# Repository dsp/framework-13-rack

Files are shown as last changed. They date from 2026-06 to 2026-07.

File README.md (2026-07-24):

# Framework 13 Mainboard — 3-Bay 1U Rack

A 19" EIA-310 1U rack that holds three Framework Laptop 13 mainboards. All parts print
without supports on a Bambu Lab H2D (325 × 320 × 325 mm). Dimensions come from
Framework's published CAD and from measurements of a physical board.

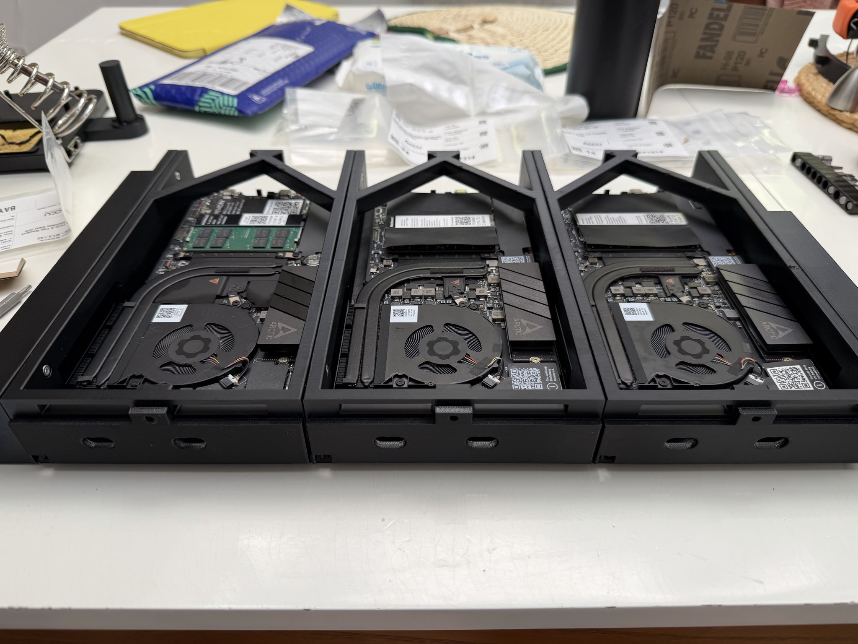
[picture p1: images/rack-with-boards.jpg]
Three Framework 13 mainboards installed in the rack


## Contents

- `stl/` — print-ready STLs, exported 2026-07-06
- `scripts/rebuild_all.py` — parametric source for all parts. It rebuilds the model in a
  fresh Fusion 360 document; set `EXPORT_STL = True` to export. Where the spec and the
  script disagree, the script is authoritative.
- `design-docs/SPEC-RevB.md` — design spec with all dimensions, stack-ups, and rationale.
  The errata blocks at the top supersede the body and record the design's revision history.
- `design-docs/framework-cad/` — Framework's reference CAD (tray STL, board drawing
  PDF/DXF, case STEP) and the scripts used to measure it
- `SCREWS.txt` — hardware list and fastener notes
- `images/` — photos of the assembled rack
- `framework.jpg` — top-view photo of the mainboard, used to locate the cooler fin stack

## Parts

| Part | Qty | Print orientation | Supports |
|---|---|---|---|
| BayModule — rack tray | 3 | standing on front face (Z = 248) | none; 8–10 mm brim |
| CarrierTray — board sled | 3 | flat, plate on bed (Z = 34.5) | none |
| SideHolderLeft — exhaust duct + rack ear | 1 | standing on front face | none |
| SideHolderRight — intake plenum + rack ear | 1 | standing on front face | none |
| RetainerPeg — board hold-down | 9 + spares | head down on bed | none |

Print in PETG or PETG-CF with 4 walls and 30–40% infill. A standard PETG profile at
0.4 mm layers works; the spec assumed 0.2 mm but the parts don't need it.

Bays printed from STLs older than 2026-07-06 have their wall vents behind the cooler
instead of over it; reprint them before running boards under load.

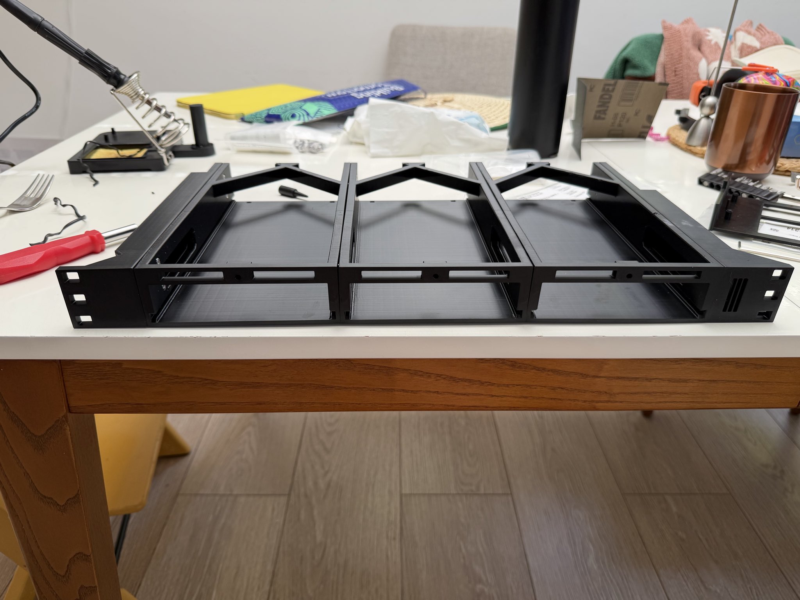
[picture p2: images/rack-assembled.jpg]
The assembled three-bay rack, front view


## Assembly

The full sequence is in SPEC-RevB.md §7; hardware is listed in SCREWS.txt.

1. Set "Power on AC attach" in each board's BIOS before racking. The power switch is
   unreachable once the board is in the rack.
2. Press the heat-set inserts: five M3 per bay (four seam, one header), four M3 in the
   left holder.
3. Bolt the bays together left to right with M3×8 screws and Ø3×8 dowel pins. Drive seam
   screws from inside the right-hand module of each pair. The left holder attaches from
   inside bay 1, the right holder from outside through its counterbores.
4. Mount each board RAM/cooler-side up on its carrier: drop it into the cage onto the
   five standoffs, then press RetainerPegs through two or three mounting holes. Two
   expansion cards face front, two face rear; USB-C power enters at the rear.
5. Slide each carrier in until the left-edge latch clicks, then lock it with its M3×8
   thumbscrew.
6. Rack with six M6 screws and cage nuts. Back the printed ears with 1.5 mm metal plates;
   tighten only until snug. Support the rear of any rack that travels.

## Board mounting

The carrier locates the board with two side nubs on the card-free long edges (0.2 mm
clearance per side) and front/rear stops between the card bays (0.5 mm). RetainerPegs
hold it down: a Ø4.2 head over the screw keep-out and a tapered Ø1.85→1.55 shaft that
press-fits into the Ø1.7 standoff pilot. The nubs and stops bear only on the board's
edges, and peg heads land where Framework's own screw heads sit. Print spare pegs; pry
under the head to remove one. The same pilots accept M2×6 self-tapping screws
(see SCREWS.txt).

The board sits component-side up at h16.5, its laptop orientation, with expansion cards
hanging below. Standard cards (5.4 mm below the PCB) clear the carrier floor by 3.1 mm;
Framework's Ethernet card (~7.4 mm) clears by about 1.1 mm. Each carrier lip has two
14 × 8 mm stadium openings on the USB-C axes (centers c 32.95 / 73.75, height h19.6,
about 2 mm above the PCB top); expansion-card ports share the same axes. The receptacle
face sits about 8.5 mm behind the lip and the card face about 6 mm, so use cables with
slim overmolds (up to about 13 × 7 mm) or fit expansion cards.

## Cooling

Air enters through the right holder's grille and each bay's front slots. The mainboard
blower exhausts through the fin stack toward the bay's left wall, out the wall vents
(y 31–105, h 13–31), and through the left holder's rear duct. Keep those vents clear.
Bay 1 sits downstream of bays 2 and 3, so watch its temperatures on first bring-up.

## Before printing

- Print the fit coupon first (about 20 minutes): groove and tongue at 0.15/0.20/0.25/0.30 mm
  clearance, the latch beam section, one standoff with a RetainerPeg, and one insert pocket.
- Verify that the PCB mounting holes pass a Ø2.0 shank; pegs and M2 screws assume it.
- Verify the Ethernet card's below-board height (7.4 mm assumed) and the board outline at
  the cage contacts (nubs at y 118.5–121.5 on the long edges, stops at c 44.4–48.7).
- Elephant-foot chamfers, floor perforation, and +0.2 mm vertical oversize on
  horizontal-axis holes are left to the slicer. Drill or ream the Ø3 dowel sockets if the
  pins won't enter.

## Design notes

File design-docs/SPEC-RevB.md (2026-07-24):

# Framework Laptop 13 Mainboard â€” 3-Bay 1U EIA-310 Rack (Parametric Design Specification, Rev B)

All dimensions mm. Target printer: Bambu Lab H2D (325 x 320 x 325). Material: PETG-CF recommended for bay modules and side holders (creep near warm electronics is the governing concern); plain PETG acceptable everywhere. All structural prints are oriented so primary loads are in-plane (see Â§9).

**Rev D change summary (physical-fit fixes against Framework official CAD — 2026-06-14):** Two flaws found on a real print, both traced to unverified board data (Open Question #1). (1) Board+cooler clash: the cooler fin-block overhangs the PCB +Y edge by ~9.0 (measured off `framework-cad/fw_main_pcb_generic_2_w_fan.pdf` sheet 4), not the 6.7 the spec assumed — the drawing's 6.7 callout is from an intermediate datum, not the PCB edge. True cross-bay envelope = 113.86 ≈ the old W_int 114 → zero clearance → the cooler banged the wall. Fix: **W_int 114→118** (bay_pitch 128→132, carrier_plate_w 121.5→125.5, groove_btb 122→126), board **shifted +9.86 in c** to center the asymmetric envelope (2.07/side), interior-standoff island Ø16→Ø12 to keep it on the plate, ear_blade_span 26.3→20.3 so the faceplate stays 482.6 (front body 430→442, margin to 450.85 now 8.85). (2) USB-C openings: the Rev C seat raise (PCB bottom h16.5) was never propagated to the tray ports — pills sat at h14.6 (1.9 BELOW the PCB). Fix: **aperture center → h18.4** (PCB-bottom+1.9, the real LOTES mid-mount receptacle center), pills span h14.4..22.4, lateral centers c 26.11/66.91 → 35.97/76.77 (follow the +9.86 board shift). Two numbers still rest on a calibrated raster read and should be caliper-checked on the physical board: the 9.0 cooler overhang and the 1.9 USB-C aperture height (see Open Questions). STLs in `stl/` are stale — re-run the script with EXPORT_STL=True in Fusion.

**REV D REVERTED (2026-06-15, supersedes the Rev D summary above and every "Rev D" parameter value below):** Rev D widened the bay to clear the cooler, which changed the outer envelope — nothing fit the bays already printed, so it was discarded. The build is the pre-Rev-D baseline (W_int 114, pitch 128, carrier plate 121.5, ear blades 26.3, front body 430, faceplate 482.6) plus a recenter that fixes both Rev D flaws inside unchanged outer dimensions: the cooler overhangs the fan-side edge 7.0 (caliper-measured, not the raster-read 9.0), so every board-locating feature shifted +6.84 in carrier-c, centering the 111.83 envelope in the 114 interior (~1.09/side); the USB-C apertures sit at c 32.95 / 73.75, center h19.6 (~2 above PCB top, user-confirmed — not Rev D's h18.4). The same pass chamfered every vent's print-top to a 12 lintel (45° corbel). `scripts/rebuild_all.py` is the authoritative geometry; where this document disagrees with the script, the script wins.

**Rev B change summary (review fixes):** sideways snap latch (old vertical latch never engaged and was unprintable); lip raised flush with plate bottom and shortened to h 32 + thumbscrew tab (carrier now truly support-free, header intake slots uncovered); lip card-cutout local coordinates corrected by the 3.75 frame-slip and enlarged to 34 x 14; groove roof chamfer deleted; rear top strap replaced by self-supporting plan-view V-brace; right holder duct moved to z 60â€“215 and turned into a REAR exhaust (fixes both the buried front screws and the hot-into-cold-aisle airflow); seam screw direction wording corrected (driven from inside the RIGHT module of each pair); seam insert holes shortened to 6.2 with M3x8 screws (no blow-through); board retention changed to M2 heat-set inserts as primary (original M1.6 x 1.5 screws are alignment-only); Ethernet card restricted to rear with plate relief pockets under all card bays; SW1 power-button / BIOS auto-power-on documented; side holders re-oriented standing on the front face; holders widened to 23 (duct area â‰¥ fin outlet) â€” front body 430, ear blades 26.3; front dowel moved to z 12 for faceplate-seam registration; strain-relief slots added at the rear; ML1220 note corrected to 11th-gen only.

---

**THERMAL ERRATA (2026-07-05, supersedes §0 orientation note and §5/§6 holder roles):** the fin-exhaust handedness stated in §0 ("blows RIGHT in every bay") is MIRRORED from physical reality. The as-built carrier maps the board as **c = 82.82 − board_y** (verified against all 5 standoffs in the live doc and by a real print — the board only mounts one way on the asymmetric hole pattern, and the user-measured 7 mm cooler overhang lands on the LOW-c edge). Therefore **every fin jet blows toward the bay's LEFT wall**. As specced, bay 1's hot jet pressurized the left "intake" plenum and blew out its front grille into the cold aisle (the exact Rev A failure §5 was fixing), while the right rear-exhaust duct received no jet. Fixed in `scripts/rebuild_all.py`: the holders' outboard boxes are SWAPPED — **LEFT holder = rear-exhaust duct** (box z 60–215, 45° prow, open rear, no grille), **RIGHT holder = front-intake plenum** (box z 0–160, 3 front + 2 outboard grille slots). Attachment hardware, plates, ear blades, EIA slots, inner vent cutouts and outer envelopes are unchanged; the right holder's two front screws (z 25 rows) are reached through sealed Ø10 tubes with Ø6 head/driver channels crossing the plenum (grip 4.0 unchanged). Cross-bay preheat now cascades 3→2→1; monitor **bay 1** (not bay 3) on first bring-up; yin-yang remains the fallback. §6's per-bay front intake and open-rear exhaust are unaffected.

**THERMAL ERRATA 2 (2026-07-06, supersedes §3 vent position and §6 "never obstruct" rule):** the fin stack is NOT centered on the board long axis — §2's cooler research and the §12 sanity check ("fins z 87.5–152.3") assumed symmetry. Measured from a calibrated top-view photo of the physical board (fin blocks 21–95 mm from the front edge) and corroborated by the fan rotor arcs in the DXF (center ≈ 46 mm forward of board center), the fin exhaust spans **bay depth z ≈ 28..101 — the FRONT half, over the fan**. The old vents (z 85–155) faced only ~16 mm of the ~74 mm fin stack; ~80 % of the jet hit solid wall. Fixed in `scripts/rebuild_all.py`: all four wall-vent cutouts (bay both walls, both holder plates) moved to **z 31..105, h 13–31** (z 31 keeps a 3 mm web to the z 25 seam-screw counterbores; corbel roof now z 102–105), and the left holder's exhaust duct pulled forward (box z 14–215, 45° prow z 14–29, cavity z 31–215.5, rear end open). Never obstruct **z 31–105** at h 13–31 on any wall. Bay outer envelope unchanged, but bays printed before this date have the vent in the wrong place for the real cooler — reprint for loaded operation.

## 0. Architecture and global coordinate conventions

**Parts (8 prints, 5 unique):**
| Part | Qty | Unique |
|---|---|---|
| Bay module ("rack-tray") | 3 | identical |
| Carrier-tray | 3 | identical |
| Side holder, LEFT (heat-set inserts on inner face; intake plenum) | 1 | unique |
| Side holder, RIGHT (through-holes counterbored from outside; rear-exhaust duct) | 1 | unique |

**Chassis frame:** origin at chassis vertical centerline, front faceplate plane, body bottom.
- `u` = across rack (left to right, viewed from front); `u_int` = per-bay interior coordinate, 0 at the bay's left wall interior face (interior spans u_int 0â€“114)
- `z` = depth, 0 at front faceplate plane, positive rearward
- `h` = height above body bottom

**Board orientation (handedness-checked, top side up):** board long axis (226.9, board X) runs front-to-back; board +X points REAR, +Y points RIGHT (pure rotation, no mirror; cooler side up). âˆ’X edge (2 expansion-card bays) faces FRONT; +X edge (2 bays) faces REAR. Cooler fin exhaust (+Y edge) blows RIGHT in every bay; blower intake faces UP.

## 1. Width budget / bay pitch

The 226.9 edge cannot run across a 3-bay split of the 450.85 opening; the 104.83 edge runs across each bay:
- Board cross-bay envelope = 104.83 PCB + 6.7 fin overhang = **111.53**
- Bay interior clear width `W_int` = **114.0** (1.235 clearance each side of the centered envelope; PCB itself: 1.235 gap left side, 7.935 gap fin/right side with fins reaching to 1.235 from the right wall)
- Wall `t_wall` = **7.0** (4.0 groove leaves 3.0 web). **Bay pitch P = 128.0.**
- 3 bays = 384.0; holder plates 8.0 each â†’ rear body 400.0; holder front sections 23.0 wide each â†’ **front body width 430.0** â‰¤ 450.85 (20.85 margin) âœ“
- Ear blades (482.6 âˆ’ 430)/2 = **26.3** per side to the 482.6 EIA faceplate âœ“

## 2. 1U height budget (verified stack â€” unchanged from Rev A, re-verified)

Panel/body height **43.2** (< 43.66 = 44.45 âˆ’ 0.794; 0.46 elephant-foot margin). From body bottom:

| Item | Height | Cumulative h |
|---|---|---|
| Bay floor | 3.0 | 3.0 (interior floor) |
| Carrier ride clearance | 2.0 | 5.0 = carrier plate bottom |
| Carrier plate | 3.0 | 8.0 = plate top |
| Standoffs (boss 5.5 + tip 1.0) | 6.5 | 14.5 = board plane |
| PCB | 1.1 | 15.6 = board top |
| Max top component (cooler stack, research 8.55) | 8.55 | 24.15 |
| **Headroom to body top** | **19.05** | 43.2 |

Check: 3.0+2.0+3.0+6.5+1.1+8.55 = 24.15; 24.15+19.05 = 43.2 âœ“. Standard expansion cards protrude 5.4 below board â†’ card bottom h 9.1 = 1.1 above plate top âœ“. The official **Ethernet card sits ~2.0 lower (h â‰ˆ 7.1)** â€” handled by plate relief pockets (Â§4) and restricted to REAR bays. Mid-rack, the unit above closes the top to a 1.25 gap: the 19 mm plenum is a distribution volume, NOT the primary intake â€” primary intake is the front (Â§6).

## 3. Bay module (x3, identical)

**Outer:** 128.0 W x 248.0 D x 43.2 H. Open top (except front header and rear V-brace), open rear center.

- **Floor:** 3.0 thick, full 114 x 248 interior. Optional Ã˜6 perforation grid mid-floor (skip groove lands, latch pocket region, zip slots). 2x zip-tie slots 4 x 4 through the floor at z 242â€“246, u_int 12â€“16 and 98â€“102 (rear cable strain relief).
- **Side walls:** 7.0 x 43.2 x 248, both sides.
- **Rail grooves** (both walls, full depth, open at front): plain rectangular â€” bottom face h 5.0, height 3.4, depth 4.0. **No roof chamfer** (Rev A's 45Â° roof chamfer deleted: unnecessary in the standing print, and it created a 0.6 ligament under the vent and destroyed Z retention; deletion restores a 4.6 solid land below the vent and full-depth retention). Groove-bottom-to-bottom 122.0. Entry chamfers 2.0 x 45Â° at the front face only.
- **Latch pocket (LEFT wall only):** blind lateral recess cut 1.8 deeper than the groove root (local wall web 7.0âˆ’4.0âˆ’1.8 = 1.2 over the pocket patch), z 10.0â€“16.5, full groove height (h 5.0â€“8.4). Receives the carrier's sideways snap (Â§4). 45Â° chamfer on the pocket's rear (print-upper) face.
- **Front frame:** opening 114.0 W x 28.0 H (h 3.0â€“31.0) plus groove break-throughs. **Front header** h 31.0â€“43.2 x 6.0 deep, full width; central boss 9.0 deep with M3 heat-set insert (Ã˜4.0 x 6.7, axis front-to-back) at module center u, h 36.0. **Two intake slots 40 x 6 at h 34.0â€“40.0**, u_int 8â€“48 and 66â€“106 (clear of the carrier's 16-wide center tab, u_int 49â€“65 â€” slots are now genuinely open with the shortened lip, Â§4).
- **Rear frame:** perimeter band 6.0 deep (z 242â€“248): bottom band h 0â€“3, wall columns full height; opening 114.0 W x 28.0 H (h 3.0â€“31.0) for rear cards/cables. **Rear top tie = plan-view V-brace** (replaces Rev A's full-width strap, which was an unprintable 114 mm bridge): two straps 8.0 wide x h 31.0â€“43.2, running at 45Â° in plan from each wall's interior face at z 180 to a center node (u_int 45â€“69) at z 242â€“248, merged with the rear band. Every layer of the standing print steps â‰¤ 0.2 laterally â€” fully self-supporting; straps sit above the 24.15 component line and above the rear opening âœ“.
- **Exhaust vent cutouts:** BOTH walls, z 85.0â€“155.0 x h 13.0â€“31.0, identical every module (aligned cross-flow relief).
- **Inter-module joint** (right wall face = insert side; left wall face = screw side):
  - 4x M3 heat-set inserts in the right wall outer face at (z, h) = (25, 18), (220, 18), (25, 36), (220, 36); hole **Ã˜4.0 x 6.2** (0.8 web â€” Rev A's 6.7/0.3 web invited melt-through). Insert 4.6 OD x 5.7 L seated ~0.5 sub-flush; still brace the wall when installing.
  - 4x Ã˜3.4 through-holes at identical positions in the left wall, counterbored Ã˜6.0 x 3.0 from the bay interior. Screws: **M3 x 8 SHCS, driven from inside the RIGHT module of each pair** (bay 2 for the 1â€“2 seam, bay 3 for the 2â€“3 seam â€” Rev A's "left neighbor" wording contradicted its own geometry). Grip 7.0âˆ’3.0 = 4.0; thread engagement â‰ˆ 3.5â€“4.0 in the insert; tip reach 4.0 < 6.2 hole âœ“. Use a ball-end or stubby driver (horizontal axis inside a 114-wide bay).
  - 2x Ã˜3.15 x 4.2 dowel sockets per joint face at **(z 12, h 38)** and (z 190, h 38); Ã˜3 x 8 steel pins. Front dowel moved from z 60 to z 12 to register faceplate segments at the seams (creep/stiffness fix â€” cheaper than a lap feature; retorque seam screws after the first week of warm operation).
  - All positions miss the groove band (5.0â€“8.4), latch pocket (z â‰¤ 16.5), and vent (z 85â€“155).
- **Chamfers:** 0.5 x 45Â° on all bed-contact edges.

## 4. Carrier-tray (x3, identical)

Carrier frame: z = 0 at lip REAR face (= bay front face when seated); `c` = 0 at plate LEFT edge; heights in chassis h. Conversions: bay u_int = c âˆ’ 3.75 (plate edge sits 3.75 inside the groove: âˆ’4.0 + 0.25 clearance); **lip-local = c + 2.75** (lip left edge at c âˆ’2.75). Cross-check: thumbscrew at lip center, lip-local 63.5 â†’ c 60.75 â†’ u_int 57 = module center = header boss âœ“.

- **Plate:** 121.5 W x 240.0 L x 3.0 thick (top h 8.0), solid (Rev A's underside ribs deleted â€” they prevented flat printing and the continuous groove support makes them unnecessary). Plate edges are the rail tongues: 3.75 engagement/side, 0.25/side lateral, 0.4 vertical clearance. 1.5 x 45Â° chamfers on tongue rear ends; 0.5 on running edges.
- **Card relief pockets (top face, 1.5 deep, 1.5 web):** 4x, 36 wide, centered c 37.5 and 78.1; front pair z 2â€“37, rear pair z 203â€“239. Leave Ã˜10 full-height collars where standoffs fall inside a pocket (standoff 2 at z 8.75/c 35.04 and standoff 3 at z 230.9/c 36.14). Pocket floor h 6.5 clears the Ethernet card bottom (h â‰ˆ 7.1) by 0.6. **Ethernet card: REAR bays only** (its RJ45 latch and 38 mm body cannot work through the front lip tunnel; the open rear frame gives full access).
- **Front lip (bezel/handle):** 127.0 W x **27.0 H (h 5.0â€“32.0)** x 4.0 thick at z âˆ’4.0â€“0, centered on the module (1.0 gaps between adjacent lips). Lip bottom is FLUSH with the plate bottom (h 5.0) â€” this is what makes the flat print legitimate. It still covers the 28-tall opening down to h 5 (2.0 open slot at h 3â€“5 = deliberate under-lip intake) and bears on the wall front faces over 6.5-wide strips each side as the insertion stop. **Center tab** 16.0 W x h 32.0â€“39.5 carries the Ã˜3.4 thumbscrew hole at h 36.0 (M3 x 8 knurled thumbscrew into the header insert; 4.0 engagement âœ“). The shortened lip leaves the header intake slots (h 34â€“40) fully exposed either side of the tab.
  - 2x card cutouts: **34.0 W x 14.0 H, h 8.0â€“22.0**, lip-local centers **40.25 and 80.85** (= c 37.5 / 78.1 â€” corrects Rev A's 3.75 frame-slip, which would have walled off both ports). No local thinning (deleted): with card faces at z 2.0 the recess from the lip outer face to the card face is 4.0 + 2.0 = **6.0** â€” plug shells insert fully; any overmold â‰¤ 33 x 13 within 6 mm of the plug seats. 45Â° chamfers on cutout tops (print bridging).
  - Latch release notch at lip bottom-left: 7.0 W x 6.0 H, lip-local 1.5â€“8.5, h 5.0â€“11.0 (push the latch tab RIGHT/inward to release).
- **Board placement:** board origin (X0, Y0) at (z 119.9, c 31.985); +X rearward, +Y right. PCB edges z 6.45 / 233.35. **Card faces protrude past the PCB edge to z â‰ˆ 2.0 (front) and z â‰ˆ 237.8 (rear)** (this resolves Rev A's self-contradiction; verify against board CAD). Rear card faces sit 4.2 ahead of the rear frame inner face (z 242); rear plugs insert through the open frame â€” chamfer the rear opening edges 1.5 x 45Â° as a blind-insertion guide.
- **Standoffs (5):** boss **Ã˜7.0** x 5.5 + concentric tip Ã˜4.2 x 1.0 (total 6.5; tip nests the board's Ã˜4.4 bottom keepout). **Primary retention: M2 brass heat-set insert** (pocket Ã˜3.2 x 4.0 from the boss top plane; tip bore Ã˜2.4 clearance) **with M2 x 5 low-profile screws** â€” engagement 5 âˆ’ (1.1 PCB + 1.0 tip) = 2.9 â‰ˆ 1.45xD âœ“. The original Framework M1.6 x 1.5 T5 screws leave ~0.4 of thread and are ALIGNMENT-ONLY (a transported carrier would drop its board). Fallback if the PCB holes reject Ã˜2.0 shanks: M1.6 x 5 screws self-threading a Ã˜1.4 x 5.0 pilot. Verify head Ã˜ â‰¤ 5.5 and height clearance per Framework keepout. Positions (carrier z, c) â€” unchanged, transforms z = 119.9 + X, c = 31.985 + Y re-verified:

| Board (x, y) | z | c |
|---|---|---|
| (28.50, âˆ’24.70) | 148.40 | 7.29 |
| (âˆ’111.15, 3.05) | 8.75 | 35.04 |
| (111.00, 4.15) | 230.90 | 36.14 |
| (âˆ’111.15, 67.05) | 8.75 | 99.04 |
| (110.50, 71.85) | 230.40 | 103.84 |

- **Snap latch â€” SIDEWAYS-acting (replaces Rev A's vertical latch, which mathematically never touched the floor and put geometry below the print bed):** cantilever beam cut into the plate at the LEFT edge, in-plane with the plate. Relief slot 2.5 W (c 1.8â€“4.3) x z 6â€“32 defines a beam c 0â€“1.8, root at z 32 pointing forward, free length 24, full plate height (h 5â€“8). Catch bump on the beam outer face: **1.5 proud beyond the plate edge** (to c âˆ’1.5 = 1.25 past the groove root), z 10â€“16, insertion ramp 35Â° (rear face), retention face 75Â° (front face). Release tab continues from the tip to z âˆ’1 through the lip notch. Mates the left-wall pocket (Â§3): engagement 1.5 âˆ’ 0.25 clearance = **1.25** on the retention face; ride deflection 1.25 over the **last ~16 mm of travel only** (the bump region enters the groove last); beam strain 3tÎ´/2LÂ² = 3Â·1.8Â·1.25/(2Â·24Â²) = **0.59 %** â€” comfortable for PETG; zero strain when seated. Everything prints in-plane, flat, support-free.

## 5. Side holders (left + right; both 23.0 wide overall, NOT identical hardware)

- **Body:** vertical plate 248.0 D x 43.2 H x 8.0 thick against the outer bay wall, plus an outboard hollow box 15.0 wide (total 23.0), walls 3.0, internal section 12.0 x 37.2 = **446 mmÂ²** (â‰¥ ~430 mmÂ² fin outlet â€” Rev A's 335 mmÂ² duct was undersized).
  - **LEFT holder = intake plenum:** box z 0â€“160, closed except a **front grille of 5 slots 3.0 W x 26 H (390 mmÂ² )**; inner plate cutout z 85â€“155, h 13â€“31 matching the bay-1 wall vent. Roof the cavity top with 45Â° corbels or accept the â‰¤12 mm bridge.
  - **RIGHT holder = REAR exhaust duct:** box **z 60â€“215**, closed front and outboard faces, **open rear end at z 215** (exhaust leaves rearward, hot side â€” Rev A blew hot air out the front grille into the cold aisle and over its own intakes). Box grows from the plate via a 45Â° prow over z 45â€“60 (self-supporting in the standing print). Inner plate cutout z 85â€“155, h 13â€“31. **No front grille.** Repositioning the box also moves BOTH screw rows (z 25 and z 220) outside the box â€” all four right-holder counterbores are now directly reachable from the outside face (fixes Rev A's two buried screws without access holes).
- **Ear blade:** coplanar with the front face, **26.3 span** x 43.2 H x 6.0 thick, R5 blend plus two triangular gussets 25 x 25 from the blade rear face onto the plate/box (bottom gusset 5.0 thick at h 0â€“5; top gusset 4.0 thick at h 39.2â€“43.2, thinned to clear the Ã˜6.0 counterbore at h 36 on the right holder). In the standing print orientation (Â§9) the blade root and gussets are loaded IN-PLANE â€” the layer-interface snap line of the Rev A flat print is eliminated. **Back each blade with a 1â€“2 mm steel or aluminium ear plate under the M6 washers (recommended) and torque M6 screws snug only (~1â€“1.5 NÂ·m)** â€” a 6 mm plastic blade will crush at full cage-nut torque.
- **Ear slots (EIA-310, 3 per U):** 10.0 W x 7.0 H, horizontal centers u = Â±232.55 (465.1 c-c; 8.75 in from the 482.6 edges; slot spans u 227.55â€“237.55, fully on the 26.3 blade spanning u 215â€“241.3 âœ“), vertical centers h 5.725 / 21.6 / 37.475 (EIA 6.35/22.225/38.1 minus the 0.625 centering gap).
- **Attachment:** same 4-hole + 2-dowel pattern as the inter-module joint (dowels z 12/190, h 38). LEFT holder: 4x heat-set inserts (Ã˜4.0 x 6.7 in the 8.0 plate, 1.3 web) + dowel sockets on the inner face; screws M3 x 8 from inside bay 1. RIGHT holder: 4x Ã˜3.4 through-holes counterbored Ã˜6.0 x 4.0 from the OUTSIDE + dowel sockets; M3 x 8 into bay 3's right-wall inserts. Grip 4.0 everywhere; engagement â‰ˆ 3.5â€“4.0 âœ“.
- **Load note:** ~2.2â€“2.7 kg on printed ears is acceptable static; PETG creep will relax insert preload â€” retorque after the first thermal cycles. **A rear support (L-bracket to the rear band or a rack shelf) is REQUIRED for any rack that is transported or slid**, recommended for all installs.

## 6. Ventilation / thermal scheme (front = intake, rear = exhaust)

- Per-board load ~28 W (prior art: 3-bay/17" build, zero heat issues).
- **Intake (front, cold aisle):** per bay: 2 header slots 480 mmÂ² + under-lip slot 114 x 2 = 228 mmÂ² (~708 mmÂ²/bay), plus card-cutout leakage; left holder front grille 390 mmÂ² feeding bay 1's left vent; top plenum is supplemental only (closed mid-rack).
- **Exhaust (rear, hot aisle):** each bay's primary exhaust is its own open rear (114 x 28); bay 3's fin jet additionally ducts through the right holder box and exits REARWARD at z 215. Bays 1/2 fin jets relieve through the aligned wall vents; residual cross-bay preheat into bay 3 is accepted at 28 W/board (most flow short-circuits out each bay's rear) â€” monitor bay-3 temps on first bring-up; alternating board orientation ("yin-yang") remains the documented fallback (open question).
- Never obstruct z 85â€“155 at h 13â€“31 on any wall.
- **Power/RTC/access:** Framework boards power-cycle via onboard SW1 (top side), inaccessible mid-rack. **Mandatory: set BIOS "Power on AC attach" and standalone-mode/chassis-intrusion (SW3) behavior BEFORE racking.** Optional Ã˜4 poke channel to SW1 deferred until SW1's position is taken from board CAD (open question). Rear PD cables: zip-tie to the floor slots (Â§3) so a cable tug loads the chassis, not the latch/thumbscrew; use 90Â° USB-C cables if possible; PD bricks live on a rear shelf/cable bar.

## 7. Assembly sequence

1. Pre-configure each mainboard's BIOS (auto power-on, standalone mode) while still in a laptop or on the bench.
2. Install heat-set inserts at ~250 Â°C: 5 per bay module (4 joint Ã˜4.0 x 6.2 + 1 header Ã˜4.0 x 6.7), 4 in the left holder (Ã˜4.0 x 6.7), 5x M2 per carrier. Brace bay walls while installing (0.8 web).
3. Dowel + screw bay1â€“bay2 then bay2â€“bay3 (M3 x 8 **from inside the right-hand module of each pair** â€” heads in bay 2 and bay 3; ball-end/stubby driver). Left holder to bay 1 (screws from inside bay 1); right holder to bay 3 (screws from outside, all four reachable).
4. Mount each mainboard to its carrier with 5x M2 x 5 (or verified fallback); fit expansion cards â€” USB-C PD at REAR for power, **Ethernet REAR only**; front and rear each expose 2 card faces.
5. Slide carriers in until the sideways latch clicks (last ~16 mm); fit M3 x 8 thumbscrews through the lip tabs.
6. Rack with 6x M6 + cage nuts, washers over the metal ear plates; snug torque only. Fit rear support. Zip-tie rear cables; retorque seam screws after the first week of warm operation.

## 8. Fastener / hardware BOM

| Item | Qty | Where |
|---|---|---|
| M3 heat-set insert, Ã˜4.6 x 5.7 (hole Ã˜4.0; Ã˜4.1â€“4.2 if tapered) | 19 (buy 25) | 12 bay joints, 3 headers, 4 left holder |
| M3 x 8 SHCS | 16 | module/holder joints (was M3 x 10 â€” shortened with the 6.2 holes) |
| M3 x 8 knurled thumbscrew | 3 | carrier locks |
| Ã˜3 x 8 steel dowel pin | 8 | joint alignment (sockets Ã˜3.15 x 4.2 at z 12/190) |
| M6 x 16 + cage nut + washer | 6 | rack ears â€” snug torque only |
| Steel/alu ear backing plate ~40 x 43 x 1.5 | 2 | under M6 washers (strongly recommended) |
| M2 brass heat-set insert (~3.5 OD x 4.0 L, hole Ã˜3.2) | 15 (buy 20) | board retention (PRIMARY) |
| M2 x 5 low-profile screws (head â‰¤ Ã˜5.5) | 15 | boards to standoffs |
| M1.6 x 1.5 Torx T5 (Framework originals) | â€” | alignment-only; NOT retention |
| ML1220 rechargeable coin cell (**Intel 11th-gen boards only**; never CR2032) | per board | RTC |
| Zip ties, small | ~6 | rear strain relief |

## 9. Print plan (all parts fit 325 x 320 x 325)

| Part | Orientation | Footprint x Z | Supports |
|---|---|---|---|
| Bay module | Standing on FRONT face | 128 x 43.2, Z = 248 | None (grooves vertical; V-brace self-supporting; latch pocket chamfered) â€” **brim 8â€“10 or draft shield** (tall narrow print; watch groove consistency near the rear) |
| Carrier-tray | Flat, plate bottom on bed (now genuinely flat: lip flush, latch in-plane, no underside features) | 127 x 244, **Z = 34.5** | None (cutout tops chamfered 45Â°) |
| Side holders | **Standing on FRONT face** (faceplate + blade on bed) â€” puts ear loads in-plane | 49.3 x 43.2, Z = 248 | None (gussets and box prow are 45Â° walls; box roofs â‰¤12 bridges or corbelled) |

**Horizontal-axis hole rule (standing prints):** model all horizontal round holes (Ã˜3.15 dowel sockets, Ã˜3.4/Ã˜4.0 joint holes) +0.2 oversize vertically (or teardrop), or drill/ream to size â€” as-printed circles droop and Ã˜3 pins will not enter Ã˜3.15 sockets otherwise.

PETG/PETG-CF, 4 walls, 5 top/bottom layers, 30â€“40 % infill, 0.2 layers. Print a 20-min fit coupon first: 30 mm groove + tongue stub at 0.15/0.20/0.25/0.30 clearances; one standoff boss with Ã˜3.2 insert pocket + M2 insert pull test (and Ã˜1.4 pilot + M1.6 x 5 fallback); a 30 mm latch-beam + pocket section.

## 10. Verification summary (all arithmetic re-run for Rev B)

- **Width:** 3x128 + 2x23 = 430 â‰¤ 450.85 (20.85 margin) âœ“; 430 + 2x26.3 = 482.6 âœ“; rear body 400 âœ“; ear holes 465.1 c-c, 8.75 inset, slots on-blade âœ“
- **Height:** 43.2 â‰¤ 43.656 âœ“; stack 3+2+3+6.5+1.1+8.55 = 24.15, headroom 19.05 âœ“; EIA hole heights 5.725/21.6/37.475 âœ“
- **Slide:** tongue 121.5 in 122.0 (0.25/side), 3.0 in 3.4 (0.4 Z, full-depth retention with chamfer deleted) âœ“; envelope 111.53 in 114.0 âœ“
- **Latch:** bump tip 1.25 past groove root; pocket 1.8 â‰¥ 1.25 + 0.3 âœ“; wall web 1.2 remains; ride deflection 1.25 â†’ strain 0.59 % âœ“; engages over the last ~16 mm only âœ“; release via lip notch âœ“
- **Lip frame conversion:** lip-local = c + 2.75; cutouts at 40.25/80.85 = c 37.5/78.1 = u_int 33.75/74.35; thumbscrew lip-local 63.5 â†’ u_int 57 = header boss âœ“ (the conversion that exposed Rev A's 3.75 error)
- **Cards:** standard card bottom 9.1 vs plate top 8.0 âœ“; Ethernet 7.1 vs pocket floor 6.5 âœ“ (rear only); 34 x 14 cutouts pass card + overmold; front recess 6.0 from lip outer face; rear faces 4.2 ahead of frame âœ“; fins z 87.5â€“152.3 inside vents z 85â€“155 âœ“
- **Fasteners:** seam grip 4.0, M3x8 tip 4.0 < 6.2 hole âœ“; holder grip 4.0 âœ“; thumbscrew 4.0 into 6.7 âœ“; M2 engagement 2.9 âœ“; counts 19 M3 inserts / 16 SHCS / 8 dowels / 15 M2 âœ“
- **Airflow:** front intake ~708 mmÂ²/bay + 390 grille; right duct 446 mmÂ² â‰¥ ~430 fin outlet; hot exhaust rear-only âœ“
- **Printability:** no part has geometry below its bed plane; no bridge > 12; largest footprint 248-tall prints fit the 325 bed âœ“

**Engineering calls where reviewers conflicted (noted):** (1) Latch â€” chose the sideways re-detail over "bigger bump + supports": one change fixes both the engagement arithmetic and the impossible print, at zero support cost. (2) Right-holder screw access â€” chose moving the duct box (z 60â€“215) over drilling access holes: the reposition was needed anyway for the rear-exhaust thermal fix and makes all four screws plainly accessible. (3) Header slots vs lip â€” chose shortening the lip (+ thumbscrew tab) over deleting the slots, preserving a real front intake for mid-rack units. (4) Carrier ribs â€” deleted rather than relocated (no clash-free location exists between the board envelope and the grooves; continuous groove support makes the solid 3.0 plate sufficient). (5) Board screws â€” M2 inserts primary per the sourced thermal review, with the M1.6 x 5 self-thread fallback retained because the PCB hole diameter for Ã˜2.0 shanks is unverified. (6) Ride gap kept at 2.0 / groove_bottom_h at 5.0 (the alternate 1.0-gap restack was unnecessary once the latch went sideways).

# Parameters
```
U_height = 44.45  # EIA 1U
panel_height = 43.2  # body and faceplate height (max 43.656)
faceplate_width = 482.6  # EIA total incl ears
post_opening = 450.85  # EIA clear opening (hard limit)
ear_hole_cc = 465.1  # horizontal hole centers
ear_hole_edge_inset = 8.75  # hole center from faceplate edge
ear_slot_w = 10.0  # horizontal slot length, M6 clearance
ear_slot_h = 7.0  # slot height
ear_hole_h1 = 5.725  # from panel bottom (6.35 - 0.625 U-gap)
ear_hole_h2 = 21.6
ear_hole_h3 = 37.475
ear_blade_span = 20.3  # Rev D: 26.3->20.3 beyond the 442 front body, per side (holds faceplate 482.6)
ear_blade_t = 6.0  # back with 1.5 metal plate under M6 washers; snug torque only
ear_gusset_leg = 20.3  # Rev D: 25.0->20.3 (follows the shorter blade)
ear_gusset_t_bottom = 5.0  # h 0-5
ear_gusset_t_top = 4.0  # h 39.2-43.2 (clears Ã˜6 cb at h 36)
bay_pitch = 132.0  # Rev D: 128->132 (W_int +4 for the real cooler envelope 113.86)
bay_outer_w = 132.0  # Rev D: 128->132
bay_outer_d = 248.0
bay_outer_h = 43.2
W_int = 118.0  # Rev D: 114->118; clears the 113.86 board+cooler cross-bay envelope with ~2.07/side
t_wall = 7.0
t_floor = 3.0
groove_bottom_h = 5.0
groove_height = 3.4  # plain rectangular roof (45deg roof chamfer DELETED)
groove_depth = 4.0
groove_btb = 126.0  # Rev D: 122->126 (= W_int + 8; tongue scheme unchanged)
groove_entry_chamfer = 2.0  # x45deg at front face only
front_opening_w = 114.0
front_opening_h = 28.0  # h 3.0-31.0
front_header_h1 = 31.0  # header band to 43.2, 6.0 deep
front_header_t = 6.0  # 9.0 at thumbscrew insert boss
header_vent_slot_w = 40.0  # two per bay
header_vent_slot_h1 = 34.0  # slot band h 34.0-40.0 (now exposed by shortened lip)
header_vent_slot_h2 = 40.0
header_vent_u1 = 8.0  # u_int spans 8-48 and 66-106 (clear of 49-65 tab zone)
header_vent_u2 = 66.0
rear_frame_t = 6.0  # z 242-248, opening 114 x 28
rear_vbrace_w = 8.0  # plan-view 45deg V-brace, h 31-43.2, wall@z180 to node z242-248 (replaces full-width strap)
rear_vbrace_node_w = 24.0  # center node u_int 45-69
rear_ziptie_slot = 4.0  # 4x4 through floor, z 242-246, u_int 12-16 and 98-102
vent_cut_z1 = 85.0
vent_cut_z2 = 155.0
vent_cut_h1 = 13.0
vent_cut_h2 = 31.0
joint_hole_z1 = 25.0
joint_hole_z2 = 220.0
joint_hole_h1 = 18.0
joint_hole_h2 = 36.0
joint_hole_dia = 3.4  # through left wall; cb 6.0 x 3.0 from own interior; screws driven from RIGHT module of pair
insert_hole_dia = 4.0  # M3 insert 4.6OD x 5.7L
insert_hole_depth_wall = 6.2  # bay seam walls (0.8 web; was 6.7/0.3)
insert_hole_depth_boss = 6.7  # header boss (9.0 deep) and left holder plate (8.0)
dowel_z1 = 12.0  # moved from 60 for front seam registration
dowel_z2 = 190.0
dowel_h = 38.0
dowel_socket_dia = 3.15  # x 4.2 deep; +0.2 vertical oversize when printed horizontal
seam_screw = 8.0  # M3 x 8 SHCS (was M3 x 10)
carrier_plate_w = 125.5  # Rev D: 121.5->125.5 (= W_int + 7.5)
carrier_plate_l = 240.0
carrier_plate_t = 3.0
carrier_ride_h = 2.0
carrier_print_z = 34.5  # tallest feature = lip tab top h 39.5 minus bed plane h 5.0
relief_pocket_w = 36.0  # 4x card relief pockets, top face
relief_pocket_d = 1.5  # leaves 1.5 web; floor h 6.5 clears Ethernet 7.1
relief_pocket_c1 = 37.5  # pocket centers (= card centers)
relief_pocket_c2 = 78.1
relief_pocket_zf1 = 2.0  # front pair z 2-37
relief_pocket_zf2 = 37.0
relief_pocket_zr1 = 203.0  # rear pair z 203-239
relief_pocket_zr2 = 239.0
relief_collar_dia = 10.0  # full-height collars around standoffs 2 and 3
lip_w = 131.0  # Rev D: 127->131 (follows pitch 132, keeps 0.5/side gap)
lip_h1 = 5.0  # lip bottom FLUSH with plate bottom (was 2.0)
lip_h2 = 32.0  # lip top (was 40.0; opening top 31.0 + 1.0 overlap)
lip_t = 4.0  # uniform (2.5 local thinning deleted)
lip_tab_w = 16.0  # center tab h 32.0-39.5 carrying thumbscrew
lip_tab_h2 = 39.5
lip_card_cut_w = 34.0  # was 32
lip_card_cut_h = 14.0  # h 8.0-22.0 (was 12, h 8.5-19)
lip_card_cut_c1 = 40.25  # lip-local = c + 2.75 (CORRECTED from 44.0)
lip_card_cut_c2 = 80.85  # CORRECTED from 84.6
lip_thumb_hole = 3.4  # at lip center (lip-local 63.5), h 36.0; M3x8 thumbscrew
lip_release_notch_w = 7.0  # lip-local 1.5-8.5, h 5.0-11.0, push latch tab inward
board_origin_z = 119.9
board_origin_c = 31.985
card_face_z_front = 2.0  # card faces overhang PCB edge 4.45 (verify vs board CAD)
card_face_z_rear = 237.8
front_recess_to_card = 6.0  # lip outer face to card face; overmold env <= 33x13
standoff_boss_dia = 7.0  # was 6.0 (insert wall)
standoff_boss_h = 7.5  # Rev C/D: boss z3..10.5 = 7.5 (raised seat); + tip 1.0 -> PCB bottom h16.5
standoff_tip_dia = 4.2
standoff_tip_h = 1.0
standoff_tip_bore = 2.4  # M2 clearance through tip
standoff_insert_hole = 3.2  # x 4.0 deep from boss top, M2 brass insert (PRIMARY)
standoff_pilot_fallback = 1.4  # x 5.0, M1.6 x 5 self-thread fallback
board_screw = 5.0  # M2 x 5 low-profile (engagement 2.9); originals M1.6x1.5 alignment-only
# NOTE (Rev C/D): the c-values below are the SUPERSEDED un-mirrored Rev B numbers. The script is
# authoritative: standoffs are mirrored (c = 82.82 - board_y) AND shifted +9.86 for cooler clearance.
# Current carrier-local (c, z): (117.38,148.40),(89.63,8.75),(88.53,230.90),(25.63,8.75),(20.83,230.40).
standoff1_z = 148.40
standoff1_c = 7.29
standoff2_z = 8.75
standoff2_c = 35.04
standoff3_z = 230.90
standoff3_c = 36.14
standoff4_z = 8.75
standoff4_c = 99.04
standoff5_z = 230.40
standoff5_c = 103.84
latch_beam_l = 24.0  # SIDEWAYS latch: root z32, tip forward, left plate edge
latch_beam_t = 1.8  # lateral (c 0-1.8), full plate height h 5-8
latch_relief_slot_w = 2.5  # c 1.8-4.3, z 6-32
latch_bump_proud = 1.5  # beyond plate edge, z 10-16; ramp 35deg / retention 75deg
latch_engagement = 1.25  # proud minus 0.25 clearance
latch_ride_deflection = 1.25  # strain 0.59 percent
latch_pocket_depth = 1.8  # into LEFT bay wall past groove root, z 10-16.5, h 5.0-8.4 (1.2 web)
latch_tab_z = -1.0  # release tab tip, through lip notch
holder_plate_t = 8.0
holder_total_w = 23.0  # was 20.0
holder_box_w = 15.0  # outboard, walls 3.0, internal 12.0 x 37.2 = 446 mm2
holder_box_left_z1 = 0.0  # left = intake plenum, front grille
holder_box_left_z2 = 160.0
holder_box_right_z1 = 60.0  # right = rear-exhaust duct (45deg prow z 45-60)
holder_box_right_z2 = 215.0  # open rear end; frees all 4 right-holder screws
holder_grille_slot_w = 3.0  # x 26 h, 5 slots, LEFT front face only (390 mm2)
holder_cb_dia = 6.0  # right holder cb x 4.0 from outside face
body_width_rear = 412.0  # Rev D: 400->412 (3x132 + 2x8 plates)
body_width_front = 442.0  # Rev D: 430->442 (3x132 + 2x23 holders); margin to 450.85 = 8.85
chassis_depth = 248.0  # +4 lip = 252 overall
board_plane_h = 16.5  # Rev C/D: raised seat; PCB bottom h16.5, PCB top h17.6
comp_top_h = 26.15  # Rev D: 24.15->26.15 (raised seat 16.5 + 1.1 PCB + 8.55 cooler)
headroom = 17.05  # Rev D: 19.05->17.05 (still > 0; panel 43.2 unchanged)
card_bottom_h = 9.1  # standard cards; Ethernet ~7.1 (REAR bays only)
plug_centerline_h = 18.4  # Rev D: 12.6->18.4. RAM-up USB-C aperture center = PCB-bottom(h16.5)+1.9. Carrier pills span h14.4..22.4. (Old script value h14.6 sat 1.9 BELOW the PCB -> the documented flaw.)
horizontal_hole_oversize = 0.2  # vertical oversize on all horizontal-axis holes in standing prints
elephant_chamfer = 0.5
brim_w = 10.0  # standing bay/holder prints (or draft shield)
```

# Open Questions
1. Board CAD verification (blocking before CAD): all board-derived dimensions came from unverifiable research data â€” validate against Framework's official mainboard drawing (FrameworkComputer/Framework-Laptop-13): standoff coordinates, card-bay footprints (note the apparent proximity of standoff 2 at c 35.04 to card bay 1 at c 37.5 â€” confirm card bodies clear the Ã˜7 bosses, adjust relief-pocket collars if not), fin span and 6.7 overhang, 8.55 cooler stack height, and the 4.45 card-face overhang past the PCB edge assumed in Rev B.
2. PCB mounting hole diameter: does it pass an M2 (Ã˜2.0) shank? If not, the M1.6 x 5 self-thread fallback becomes primary â€” confirm M2/M1.6 screw head Ã˜ â‰¤ 5.5 and height clearance against the board-top keepout.
3. SW1 power-button position (board X,Y) from CAD â€” decide whether to add the optional front poke channel/plunger, or rely solely on BIOS auto-power-on (documented as mandatory either way). Confirm SW3 chassis-intrusion behavior for standalone boards.
4. Ethernet expansion card exact envelope (38 deep, ~2 below standard bottom â€” community-sourced): confirm against a physical card; verify the rear opening and relief pocket accommodate it with the RJ45 latch operable.
5. Rear support bracket design (required for transportable racks): simple printed L-bracket to the rear band vs rack shelf â€” not yet detailed.
6. Bay-3 preheat: first bring-up should log per-board temps under sustained load; if bay 3 runs >10 C over bay 1, implement the yin-yang (alternating orientation) fallback or per-bay rear baffles.
7. Fit-coupon results gate final clearances: groove/tongue (0.15-0.30 sweep), M2 insert pull-out in the Ã˜3.2 boss pocket, sideways latch click force, and as-printed horizontal hole droop (validate the +0.2 oversize rule on the H2D).
8. CAD-level clash check of the right-holder top gusset (h 39.2-43.2) against the Ã˜6.0 counterbore at h 36 (0.2 nominal clearance as specified) â€” notch the gusset locally if the fillet/R5 blend intrudes.

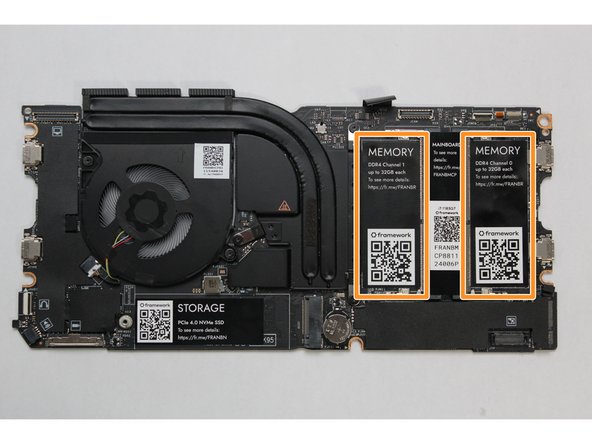
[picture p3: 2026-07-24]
framework.jpg

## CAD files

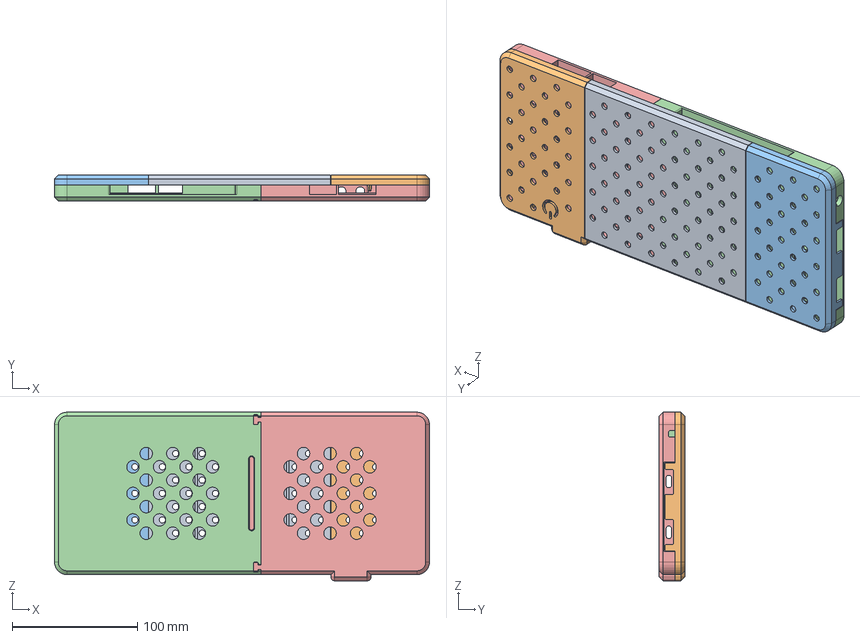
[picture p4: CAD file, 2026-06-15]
design-docs/framework-cad/printable_case_full.stp
299.6 x 20.5 x 134.8 mm
9_FW_TOP_COVER_MAIN_1
9_FW_TOP_COVER_RIGHT_3
9_FW_TOP_COVER_LEFT_1
9_FW_BOT_COVER_L_1
9_FW_BOT_COVER_R_1
CONNECT_PIN_1 x 10

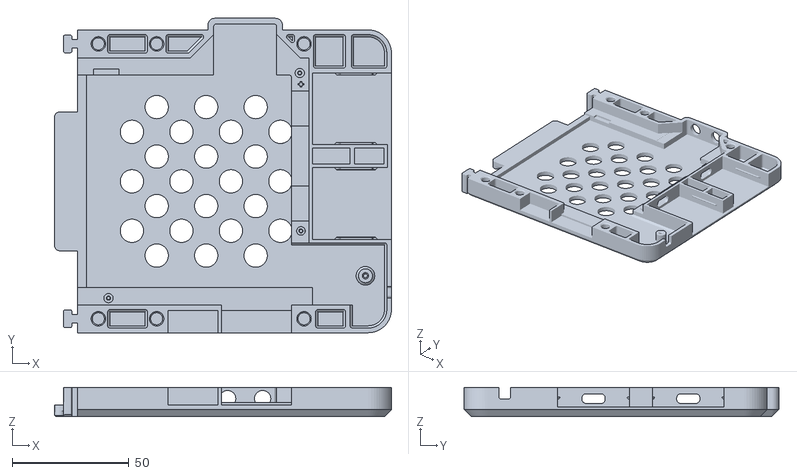
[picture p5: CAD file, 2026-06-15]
design-docs/framework-cad/bottom_cover_r_full.stl
144.5 x 134.8 x 12.5

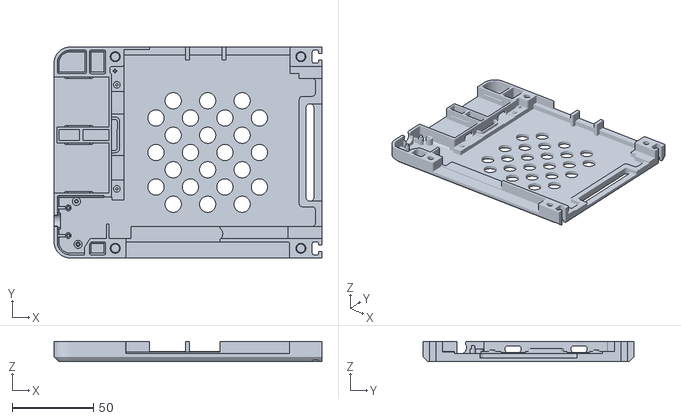
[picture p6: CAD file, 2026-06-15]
design-docs/framework-cad/bottom_cover_l_full.stl
164.8 x 129.8 x 12.5

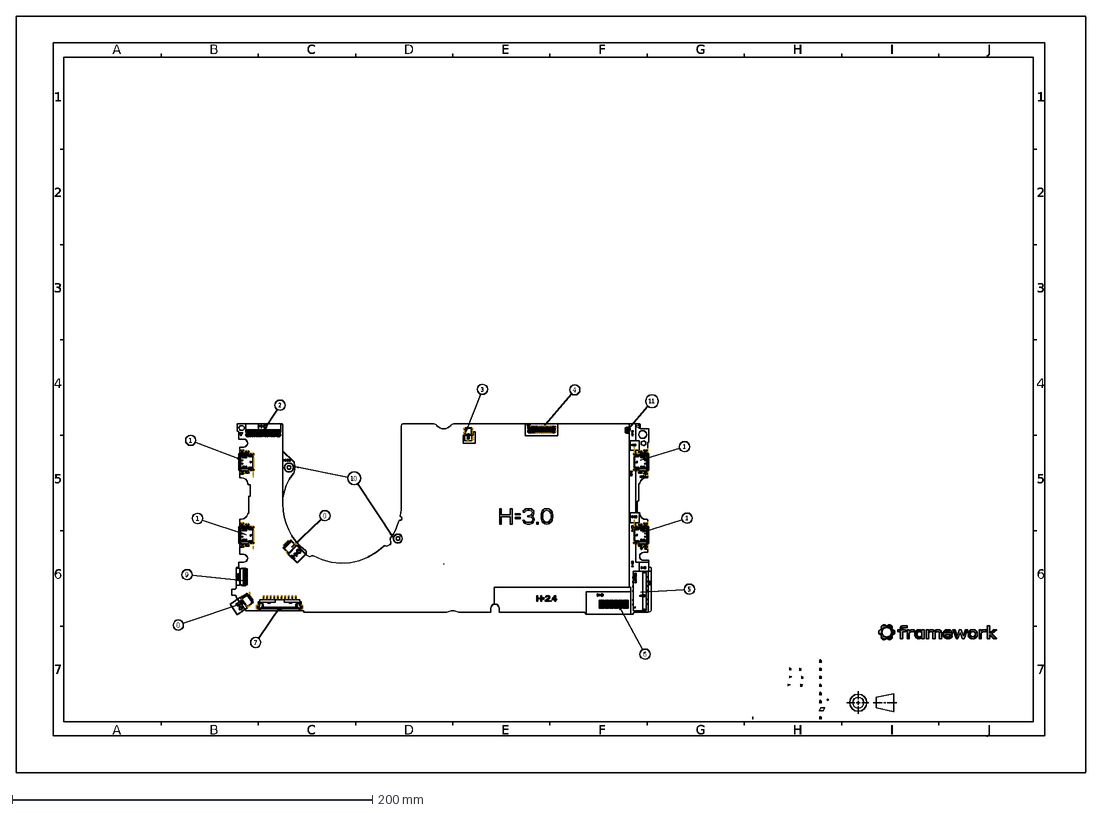
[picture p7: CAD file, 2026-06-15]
design-docs/framework-cad/fw_main_pcb_generic_2_w_fan_1.dxf
A
7
6
5
C
B
D
1
4
3
2
E
F
G
H
I
J
8
9
10
11

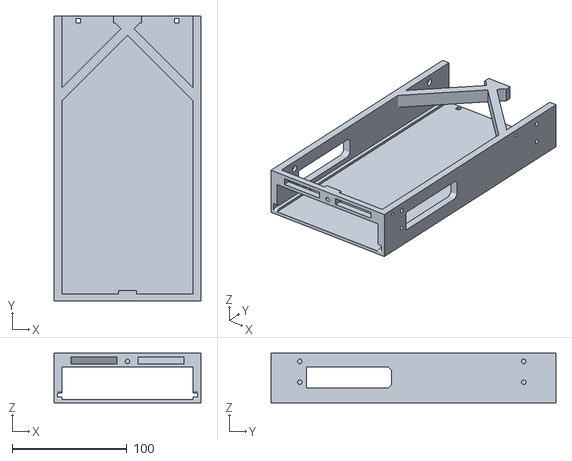
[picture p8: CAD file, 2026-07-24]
stl/BayModule.stl
128.0 x 248.0 x 43.2

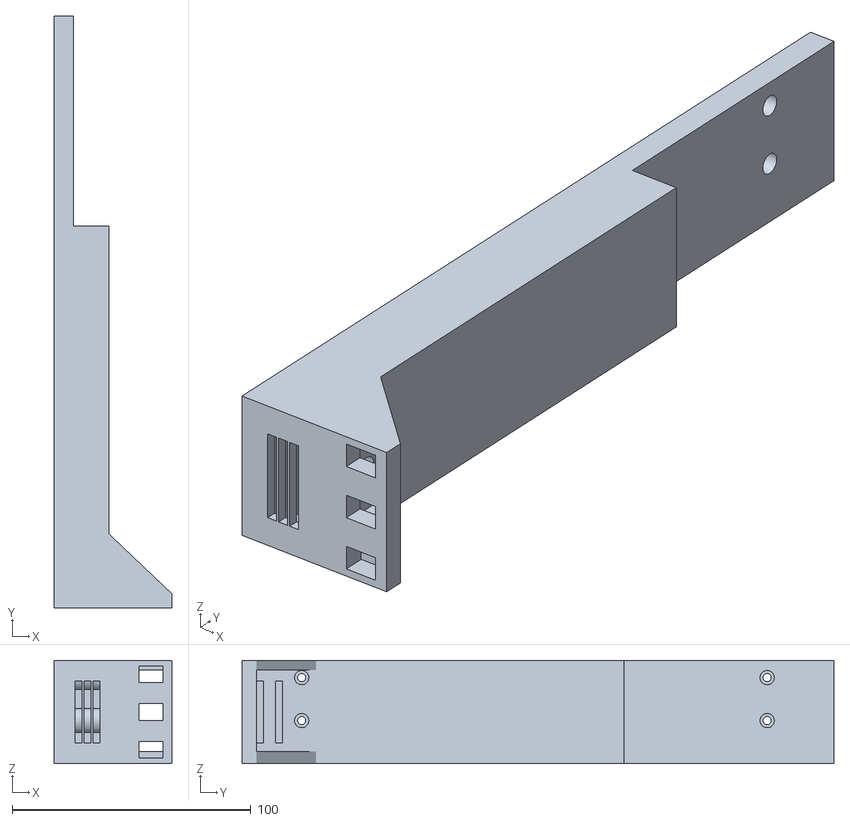
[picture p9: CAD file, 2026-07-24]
stl/SideHolderRight.stl
49.3 x 248.0 x 43.2

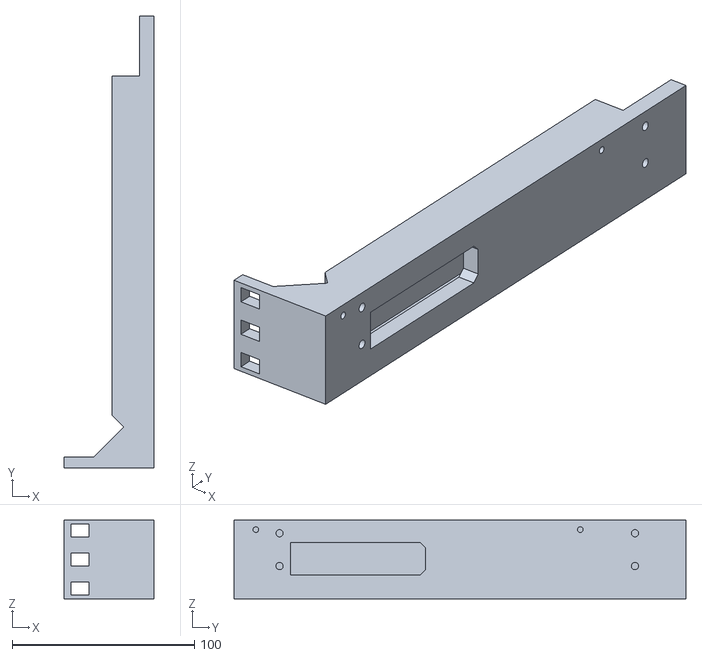
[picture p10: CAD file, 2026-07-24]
stl/SideHolderLeft.stl
49.3 x 248.0 x 43.2

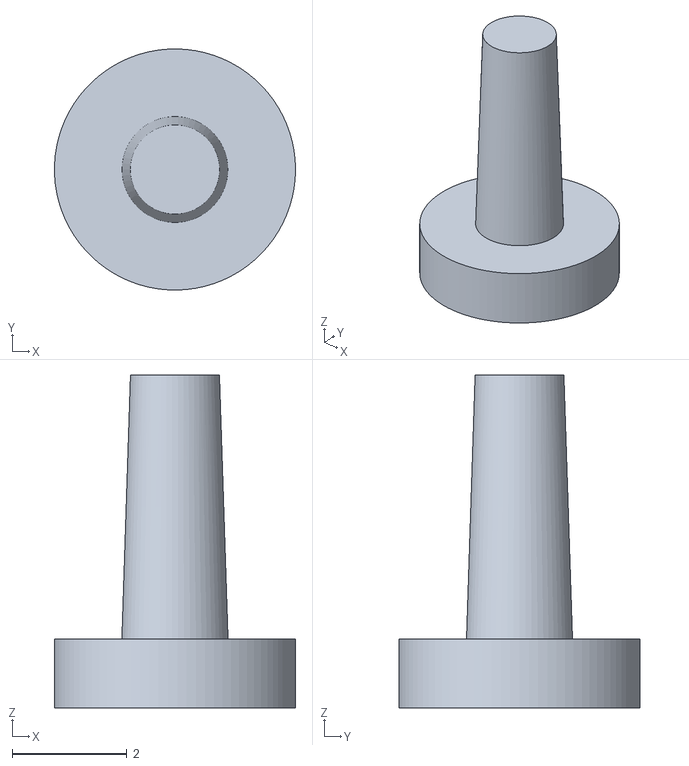
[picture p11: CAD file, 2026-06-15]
stl/RetainerPeg.stl
4.20 x 4.20 x 5.80

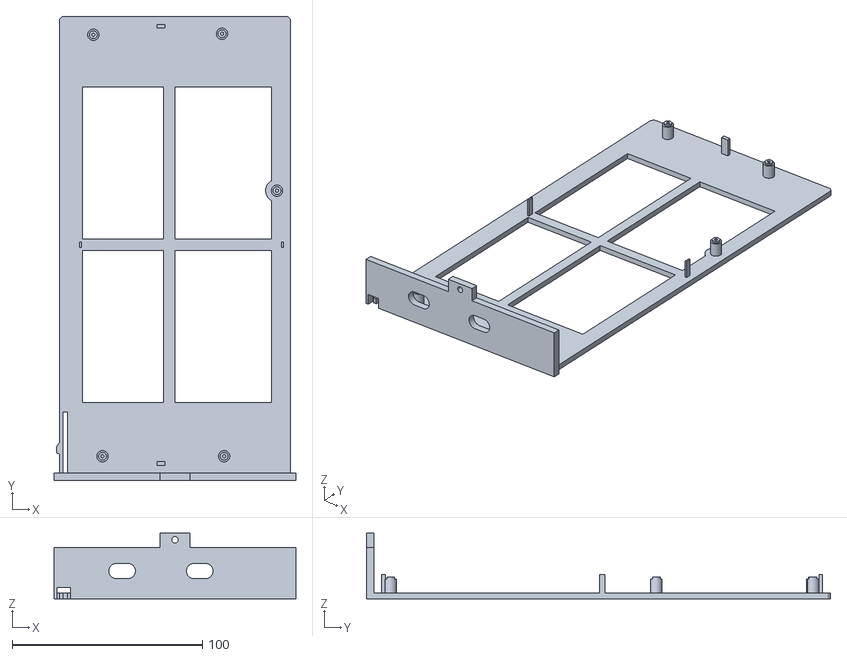
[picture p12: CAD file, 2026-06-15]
stl/CarrierTray.stl
127.0 x 244.0 x 34.5

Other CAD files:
design-docs/framework-cad/tray.scad

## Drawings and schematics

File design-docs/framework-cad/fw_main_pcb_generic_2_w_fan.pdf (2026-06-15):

1

2

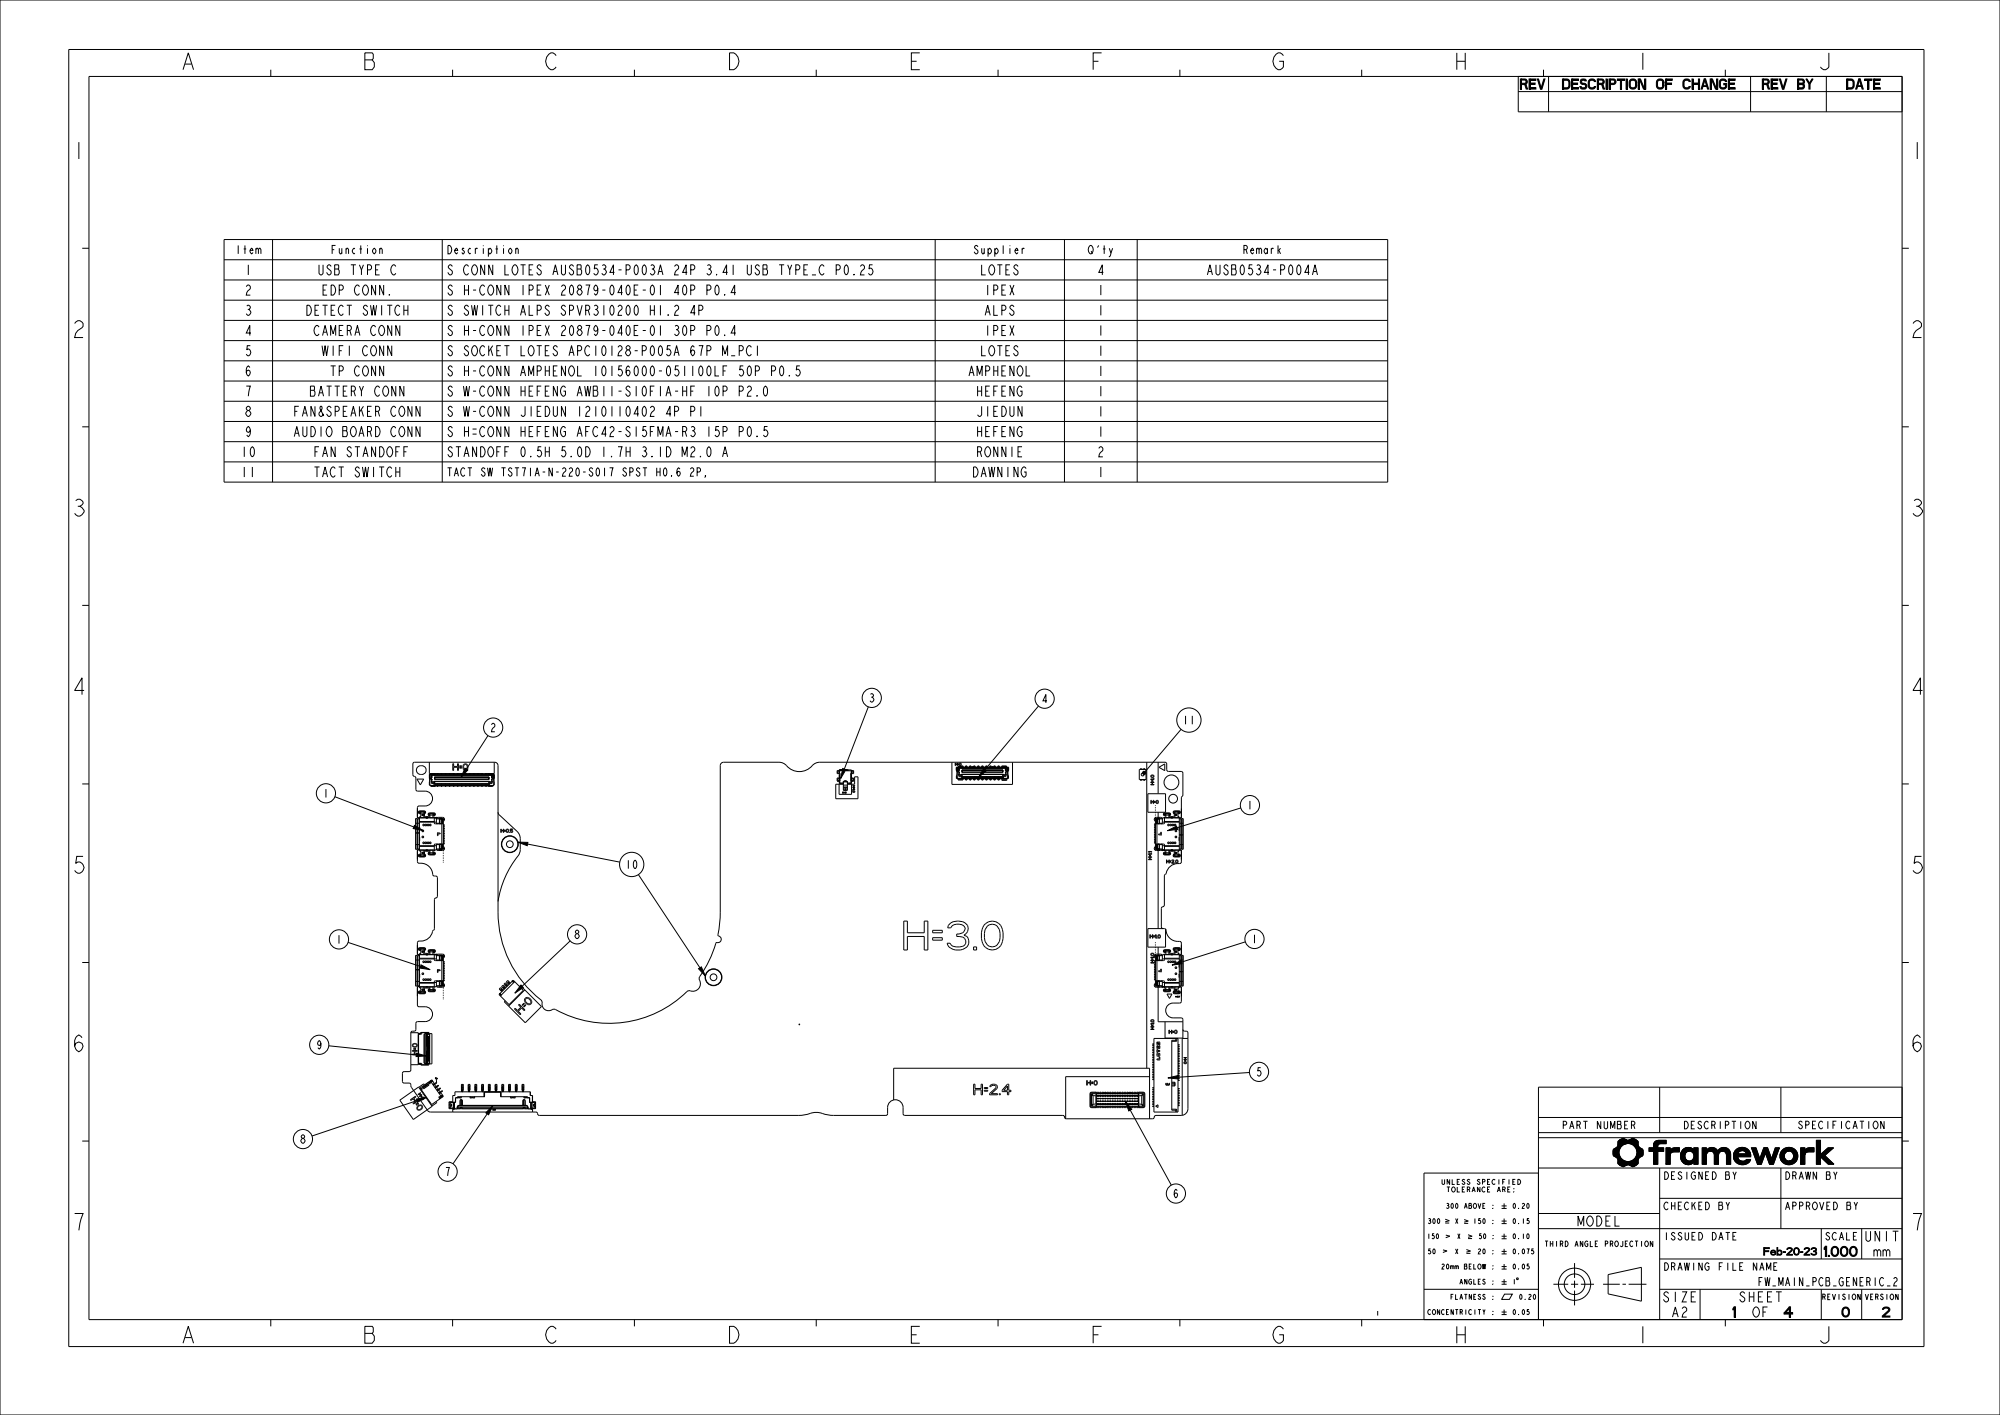
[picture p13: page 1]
REV; DESCRIPTION OF CHANGEREV BY; DATE; PART NUMBER; DESCRIPTION; SPECIFICATION; DESIGNED BY; DRAWN BY; CHECKED BY; APPROVED BY; MODEL; ISSUED DATE; SCALEUNIT; Feb-20-23 1.000; FW_MAIN_PCB_GENERIC_2; SIZE; SHEET; REVISION VERSION; UNLESS SPECIFIED TOLERANCE ARE:; 300 ABOVE :; 20mm BELOW :; ANGLES :; FLATNESS :; CONCENTRICITY : 0.05; Item; Function; Description; Supplier; Remark; USB TYPE C; S CONN LOTES AUSB0534-P003A 24P 3.41 USB TYPE_C P0.25; LOTES; AUSB0534-P004A; EDP CONN.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

THIRD ANGLE PROJECTION

DRAWING FILE NAME

B

C

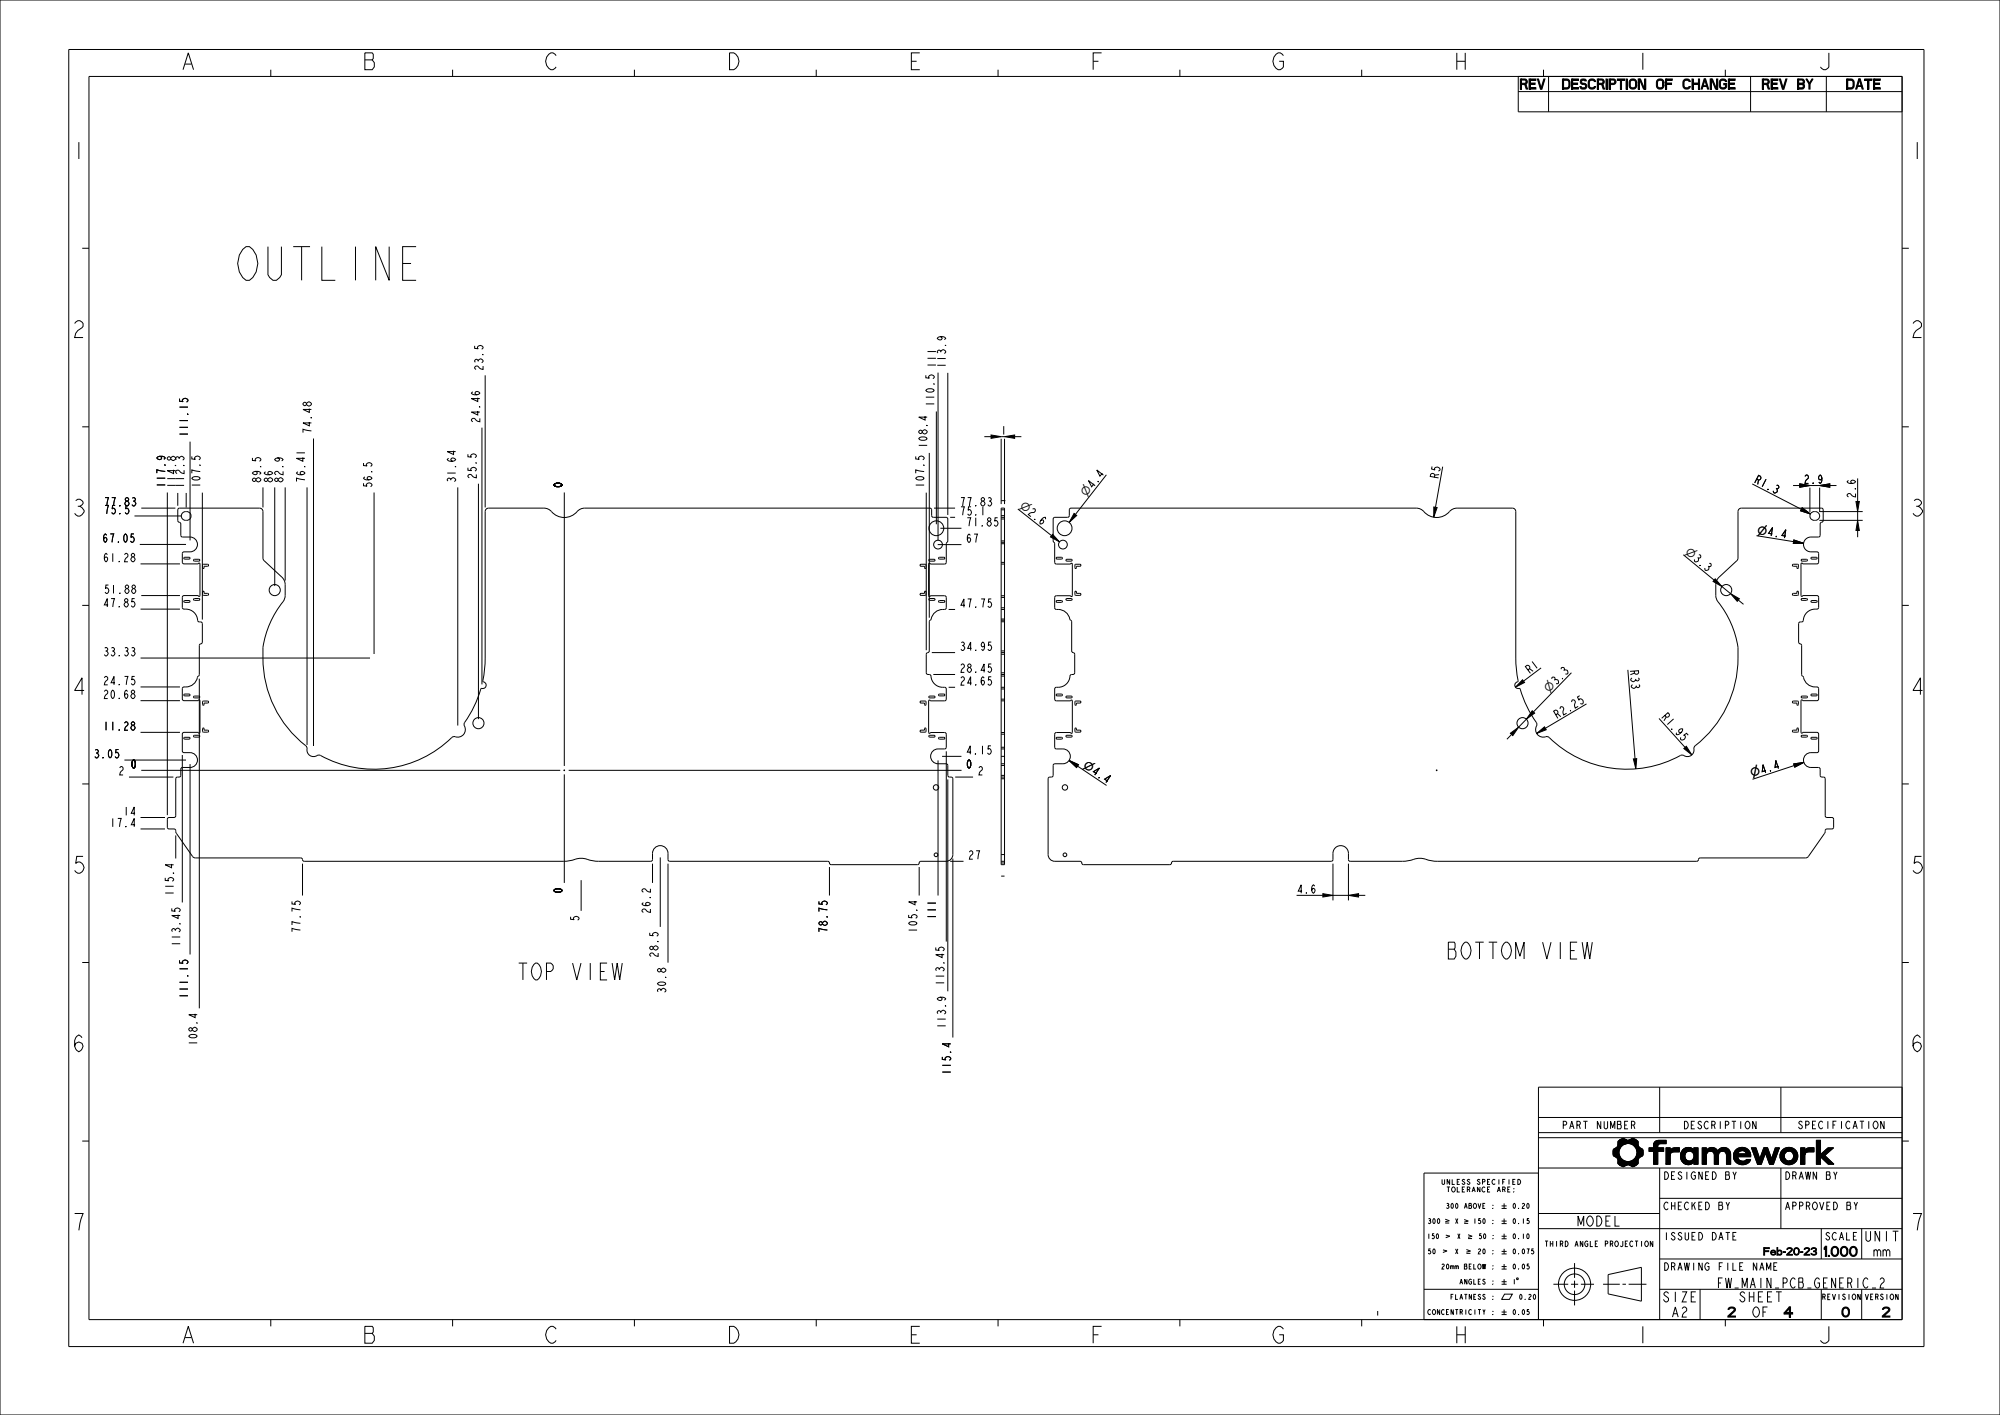
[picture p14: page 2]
PART NUMBER; DESCRIPTION; SPECIFICATION; MODEL; Feb-20-23; FW_MAIN_PCB_GENERIC_2; UNLESS SPECIFIED TOLERANCE ARE:; 300 ABOVE :; 20mm BELOW :; ANGLES :; OUTLINE; TOP VIEW; BOTTOM VIEW

DESIGNED BY | DRAWN BY

CHECKED BY | APPROVED BY

ISSUED DATE | SCALEUNIT

THIRD ANGLE PROJECTION

DRAWING FILE NAME

1

2

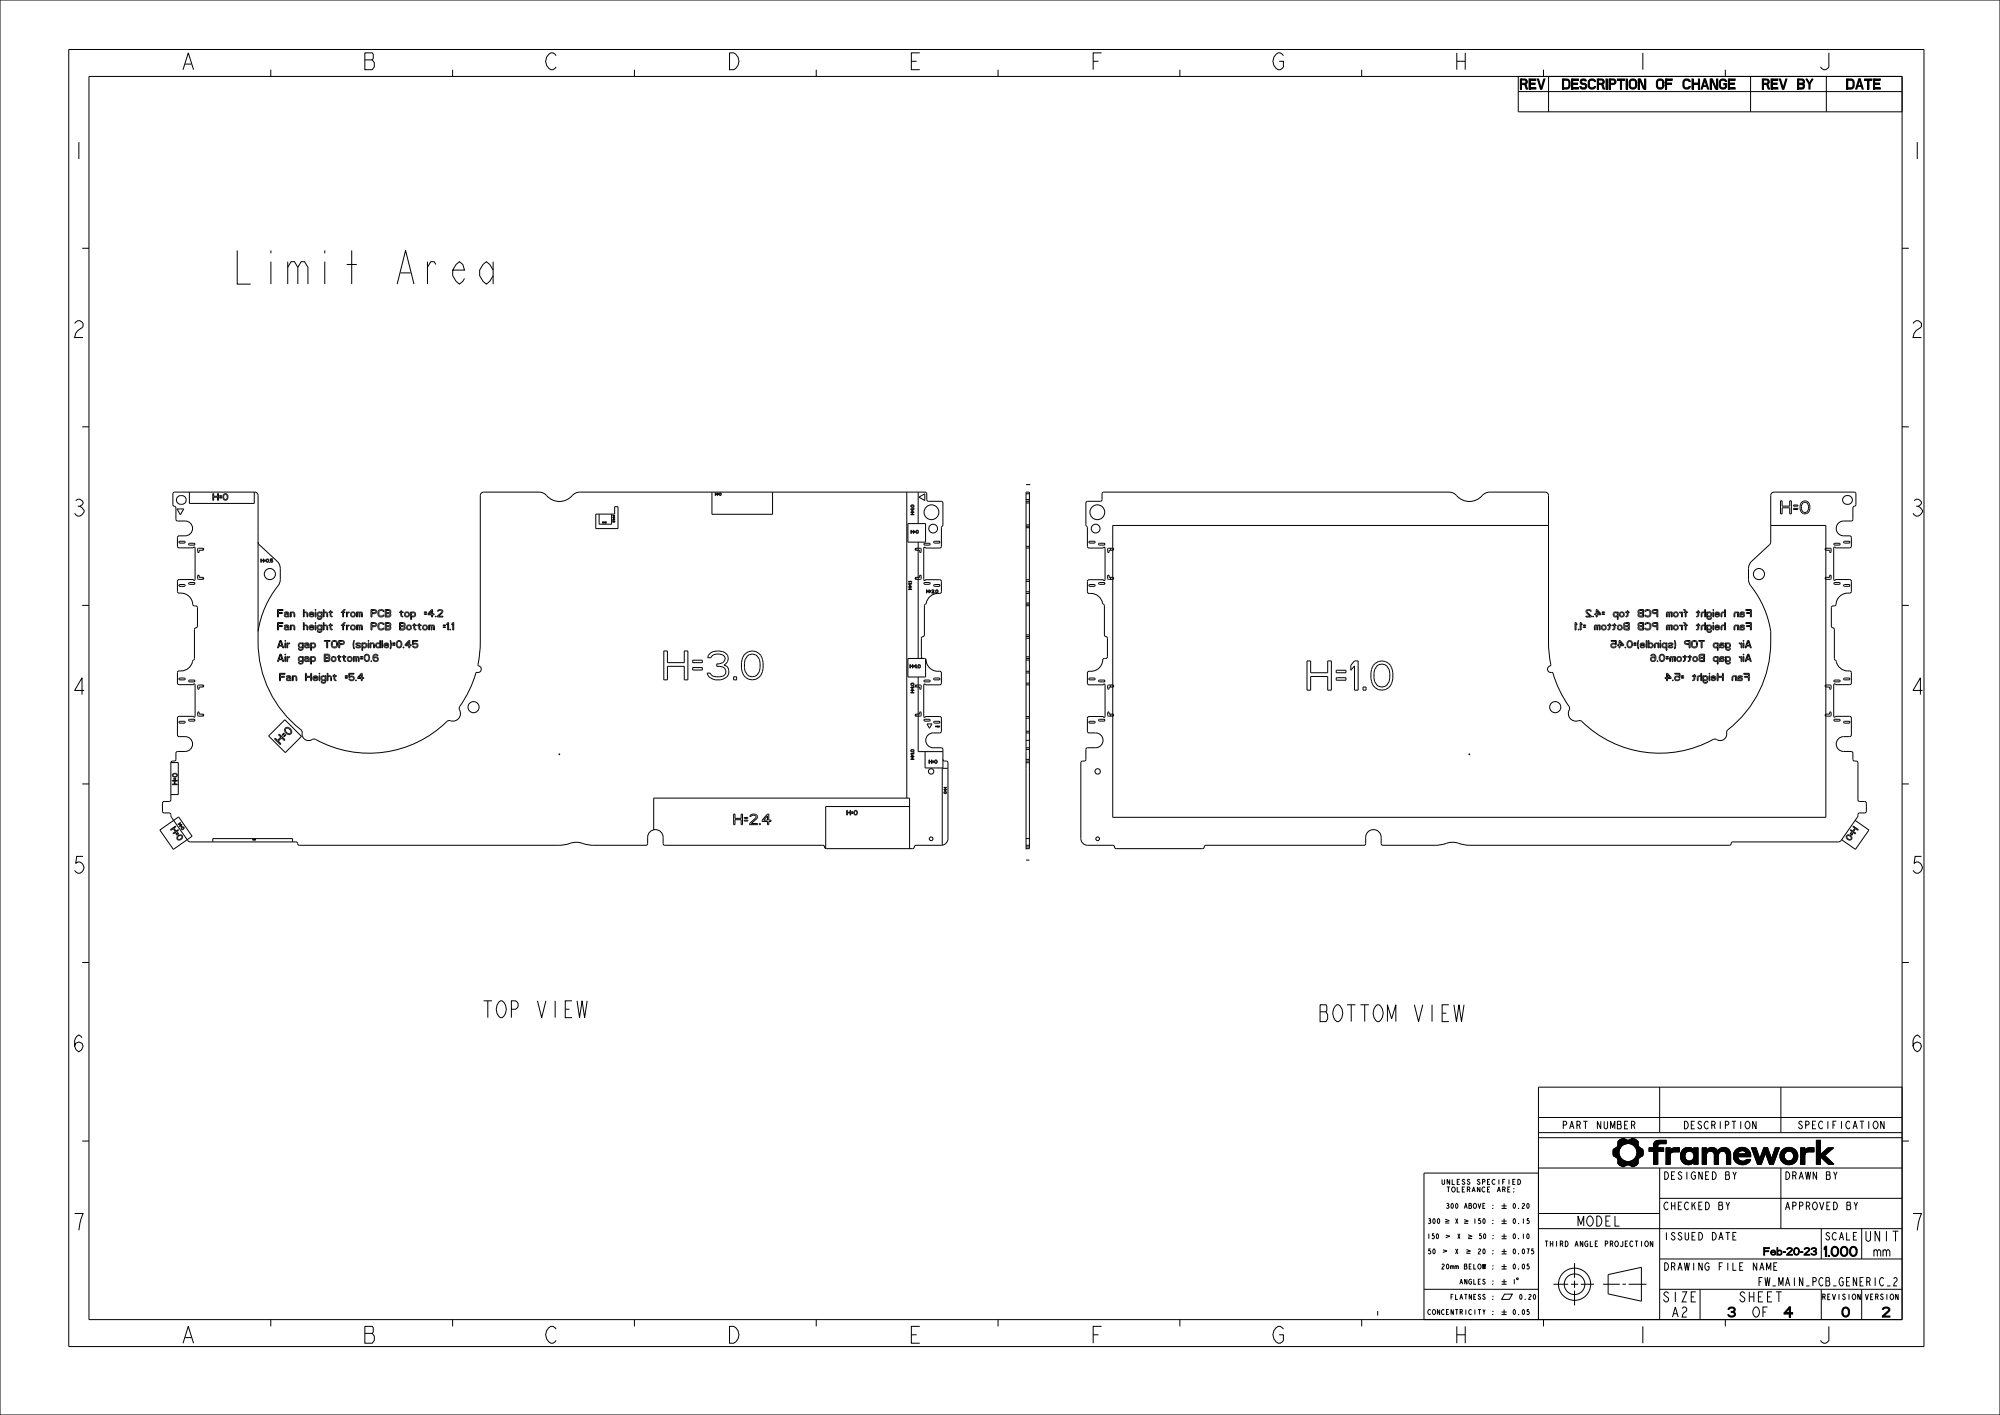
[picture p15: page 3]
PART NUMBER; DESCRIPTION; SPECIFICATION; MODEL; Feb-20-23; FW_MAIN_PCB_GENERIC_2; UNLESS SPECIFIED TOLERANCE ARE:; 300 ABOVE :; 20mm BELOW :; ANGLES :; Limit Area; TOP VIEW; BOTTOM VIEW

DESIGNED BY | DRAWN BY

CHECKED BY | APPROVED BY

ISSUED DATE | SCALEUNIT

THIRD ANGLE PROJECTION

DRAWING FILE NAME

1

2

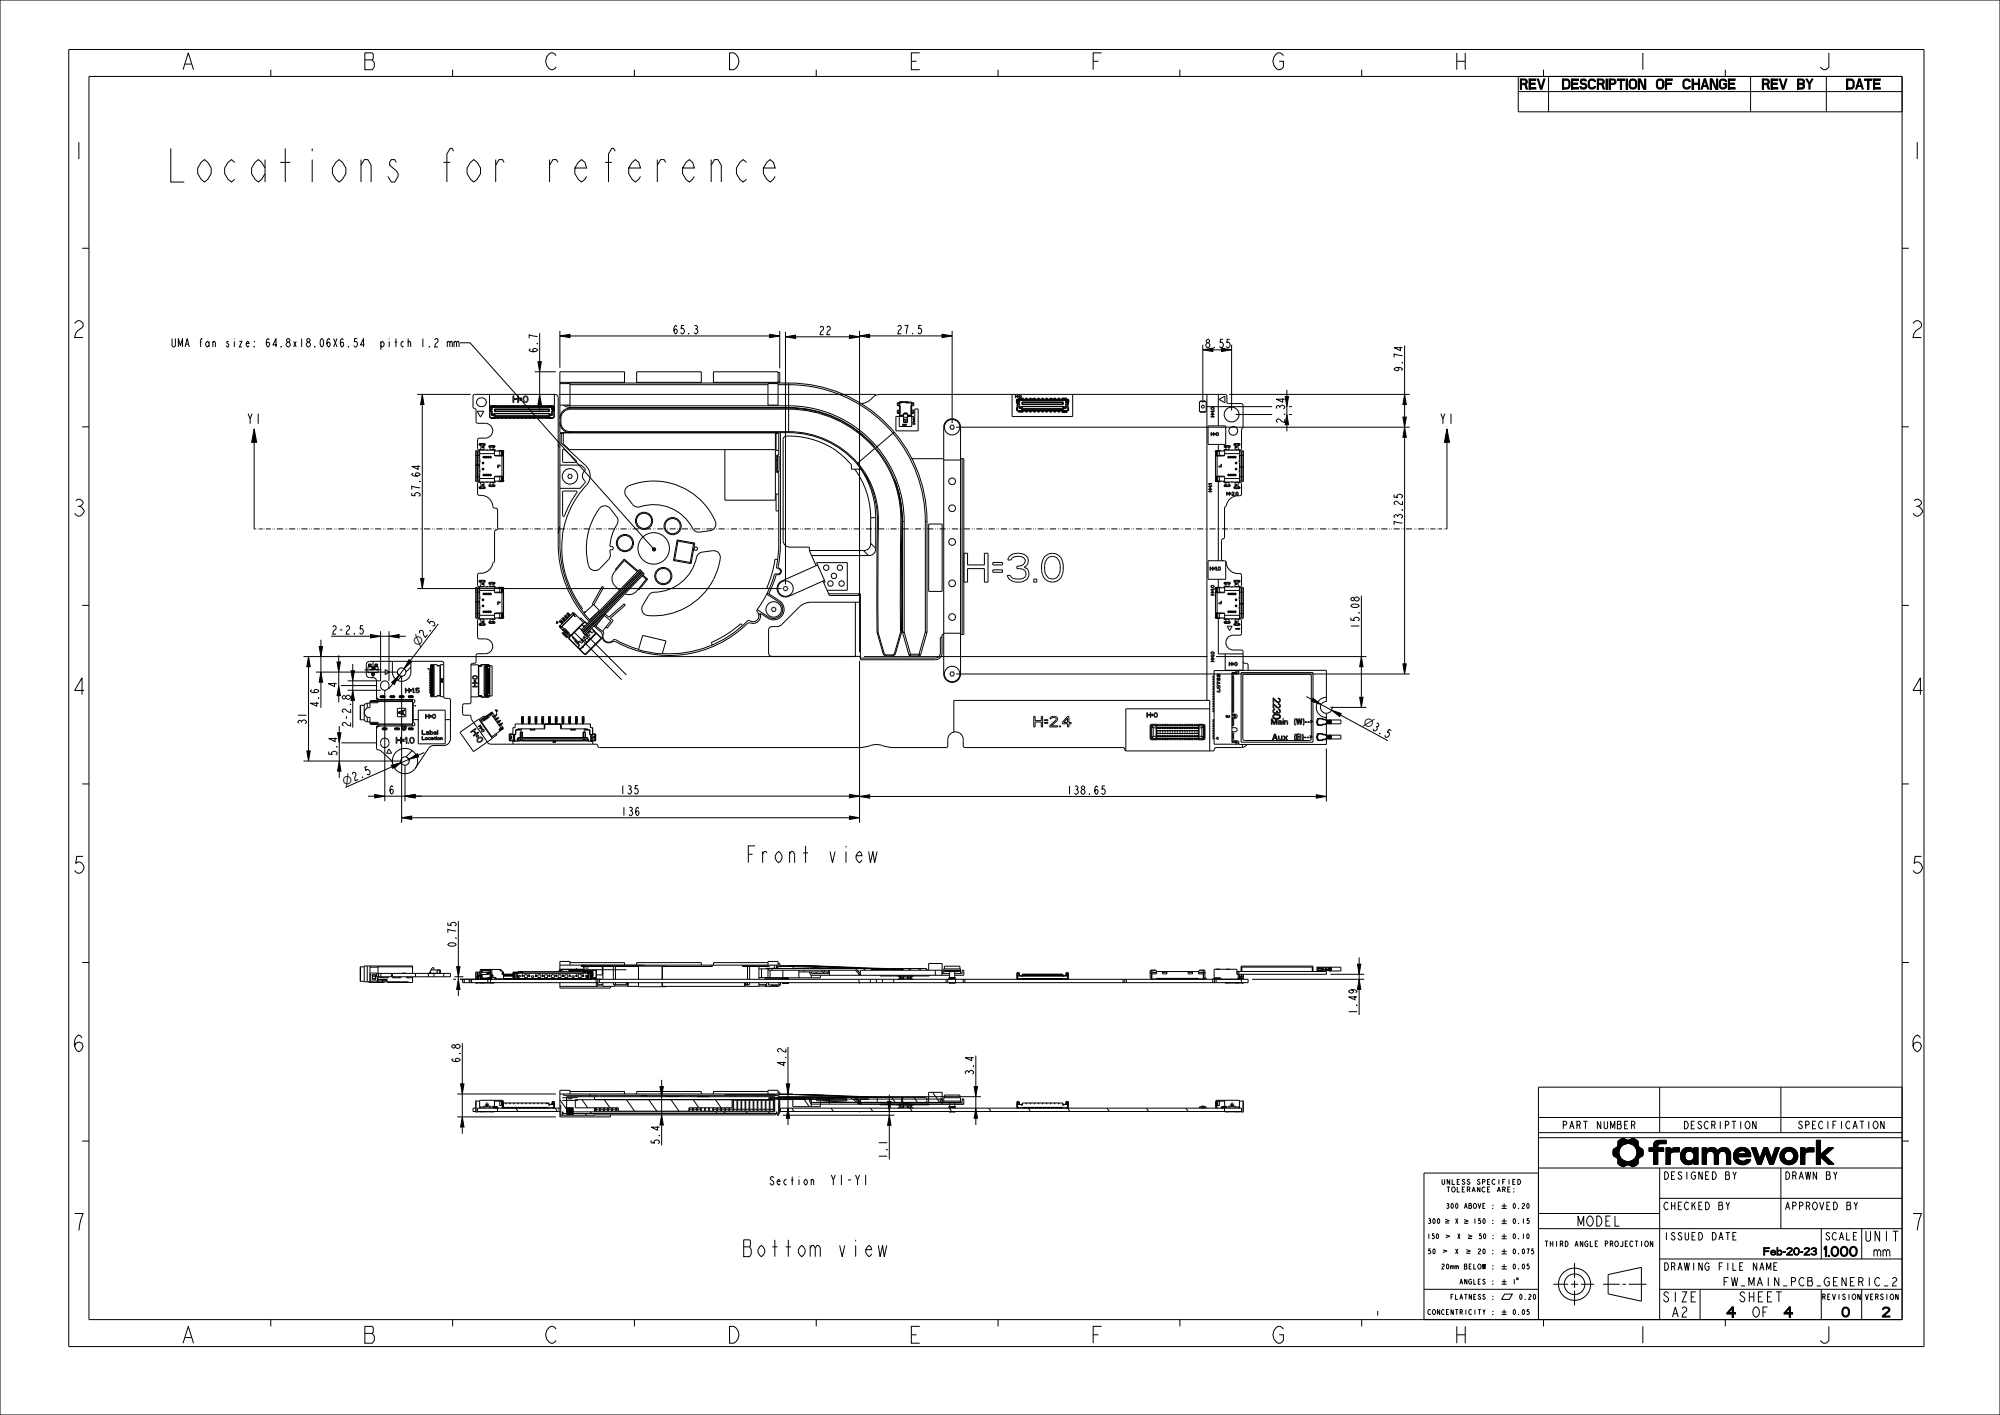
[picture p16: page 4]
PART NUMBER; DESCRIPTION; SPECIFICATION; DESIGNED BY; DRAWN BY; CHECKED BY; APPROVED BY; MODEL; ISSUED DATE; SCALEUNIT; Feb-20-23 1.000; FW_MAIN_PCB_GENERIC_2; UNLESS SPECIFIED TOLERANCE ARE:; 300 ABOVE :; 20mm BELOW :; ANGLES :; Bottom view; Front view; Section

Locations for reference

UMA fan size: 64.8x18.06X6.54 pitch 1.2 mm

THIRD ANGLE PROJECTION

DRAWING FILE NAME

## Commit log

2026-06-15 Initial commit: Framework 13 mainboard 3-bay 1U rack
    Parametric 3-bay 1U EIA-310 rack for Framework Laptop 13 mainboards: SPEC Rev B, Fusion rebuild script, reference CAD, and printable STLs.
    Bay and side-holder wall vents corbelled to a 12mm self-supporting lintel so all parts print front-face-down without support; all 5 STLs re-exported from the script. Bay outer size unchanged (128 x 2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
    [BayModule.stl, CarrierTray.stl, RetainerPeg.stl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]
2026-07-24 Thermal fixes: swap holder duct/plenum roles, move vents to the real fin stack
    Two errata found against the physical board (2026-07-05/06):
    - The fin jets blow toward the LEFT wall (the spec's handedness was
    mirrored), so the left holder now carries the rear-exhaust duct and the
    right holder the intake plenum. Only the two holders changed shape.
    - The fin stack sits in the FRONT half of the bay (y 28..101, measured
    from framework.jpg, corroborated by the DXF fan arcs via fanlocate.js),
    not mid-board. All wall vents and holder cutouts moved from y 85-155 to
    y 31-105; the left duct starts at y 14. Bays printed before this vent
    the wrong spot and need reprinting for loaded operatio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
    [BayModule.stl, SideHolderLeft.stl, SideHolderRight.stl]
2026-07-24 Docs: reconcile with the as-built design; rewrite README and SCREWS.txt
    The README and spec still presented the abandoned Rev D (wider bay,
    pitch 132) as current and flagged the STLs stale. In reality Rev D was
    reverted 2026-06-15 in favor of the recenter fix (+6.84 board shift,
    USB-C at h19.6, outer envelope unchanged), and all STLs were re-exported
    2026-07-06.
    - SPEC-RevB.md: add a REV D REVERTED errata block; the script is
    authoritative where the spec body disagrees.
    - README.md: rewrite. Correct revision history (Rev C, Rev D abandoned,
    recenter, both thermal errata), current USB-C numbers (c 32.95/73.75,
    h19.6), drop the stale-STL warning and the reference to the gitignored
    tra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
2026-07-24 Copyedit README and SCREWS.txt per The Elements of Style
    Recast two sentence fragments in the Rev C entry, replace two colloquial
    "so" conjunctions, make the intro active, and repair the dangling "snug
    them only" / "snug torque only" endings in both files.
    Claude-Session: https://claude.ai/code/session_017NDR2y9Dw1LF2co9dS274v
2026-07-24 README: drop the revision history, match Framework's plain doc style
    The revision narrative duplicated the spec errata, which the Contents
    section now points to instead. Replaced editorializing (real hardware,
    committing plastic, bolded warnings) with plain statements, added a
    short Cooling section covering the airflow path and the bay 1
    bring-up note, and moved the pre-2026-07-06 reprint notice next to
    the parts table where builders will see it.
    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
2026-07-24 README: parts print fine at 0.4 mm layers with a standard PETG profile
    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
2026-07-24 Add photos of the assembled rack to the README
    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
